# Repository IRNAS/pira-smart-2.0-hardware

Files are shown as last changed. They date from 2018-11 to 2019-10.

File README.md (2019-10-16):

# pira-smart-3.0-hardware

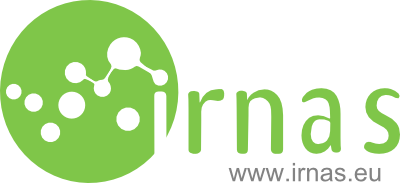
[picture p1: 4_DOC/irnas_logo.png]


PIRA Smart is a multifunctional device that can be used in any IoT project.

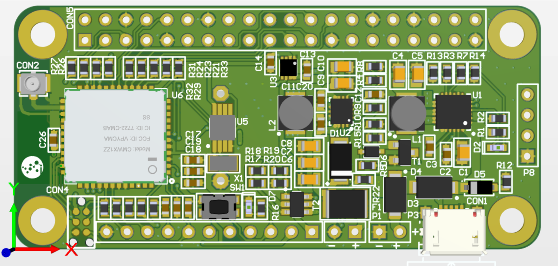
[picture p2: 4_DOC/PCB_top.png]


## Folder structure
 * folder [1_SCHEMATIC](https://github.com/IRNAS/pira-smart-2.0-hardware/tree/development/1_SCHEMATIC) includes Altium schematic files and PDF schematic
 * folder [2_PCB](https://github.com/IRNAS/pira-smart-2.0-hardware/tree/development/2_PCB) includes Altium PCB file, PDF PCB print and PDF 3D PCB print
 * folder [3_OUTPUT_FILES](https://github.com/IRNAS/pira-smart-2.0-hardware/tree/development/3_OUTPUT_FILES) includes Gerber and NC Drill files, PDF Assembly file and Bill of Material
 * folder [4_DOC](https://github.com/IRNAS/pira-smart-2.0-hardware/tree/development/4_DOC) includes 3D step model of PCB and photos of device
 * folder [5_ALTIUM_FILES](https://github.com/IRNAS/pira-smart-2.0-hardware/tree/development/5_ALTIUM_FILES) incudes all Altium Designer files (Libraries, Output job, Project document, ...)
 * folder [6_RELEASE](https://github.com/IRNAS/pira-smart-2.0-hardware/tree/development/6_RELEASE/pira-smart-PCB/v2_1) includes latest release [version 2.1](https://github.com/IRNAS/pira-smart-2.0-hardware/tree/development/6_RELEASE/pira-smart-PCB/v2_1)

## Specification

Device consists of:
 * Microcontroller module Murata Type ABZ - CMWX1ZZABZ:
   * Microcontroller STM (STM32L073)
   * LoRa connectivity Semtech (SX1276)
 * BLE - RN4871
 * RTC - ISL1208IU8Z-T7A
 * EEPROM with EUI - 24AA02E48T-I/OT
 * LDO regulator - MCP1810T-30I/J8A
 * Boost converter - TPS630701RNMT
 * Battery charger - BQ24296RGET
 * RPi connector
 * GPIO header
 * Tag connect for programming TC2030

Block diagram

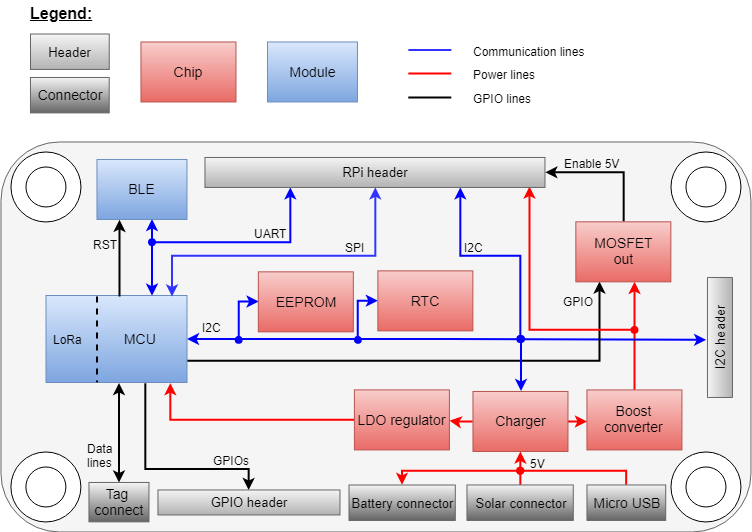
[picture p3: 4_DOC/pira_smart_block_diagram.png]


Features:
 * Single cell LiPo cell charging of up to 3A (multiple 18650 cells supported)
 * Solar panel charging (Voltaic systems 6W panels in parallel recommended)
 * USB charging
 * Advanced current limiting, to support wide array of chargers
 * Precise charging control via I2C (BQ24296RGET)
 * Battery temperature protection with thermistor
 * Battery reverse polarity protection and fuse (3A)
 * High-current battery output MOSFET
 * LoRa communication module with micro RF connector
 * Advanced power scheduling for robust applications:
   * ISL1208 RTC for configurable scheduled boot and timekeeping, with battery backup power supply to save power of the main battery
   * Configurable power-up sources (RTC, charging, etc.)

Dimensions:
 * Lenght: 65 mm
 * Height: 30 mm
 * PCB thickness: 1.6 mm

## License

All our projects are as usefully open-source as possible.

Hardware including documentation is licensed under [CERN OHL v.1.2. license](http://www.ohwr.org/licenses/cern-ohl/v1.2)

Firmware and software originating from the project is licensed under [GNU GENERAL PUBLIC LICENSE v3](http://www.gnu.org/licenses/gpl-3.0.en.html).

Open data generated by our projects is licensed under [CC0](https://creativecommons.org/publicdomain/zero/1.0/legalcode).

All our websites and additional documentation are licensed under [Creative Commons Attribution-ShareAlike 4 .0 Unported License](https://creativecommons.org/licenses/by-sa/4.0/legalcode).

What this means is that you can use hardware, firmware, software and documentation without paying a royalty and knowing that you'll be able to use your version forever. You are also free to make changes but if you share these changes then you have to do so on the same conditions that you enjoy.

Koruza, GoodEnoughCNC and IRNAS are all names and marks of Institut IRNAS Race. 
You may use these names and terms only to attribute the appropriate entity as required by the Open Licences referred to above. You may not use them in any other way and in particular you may not use them to imply endorsement or authorization of any hardware that you design, make or sell.

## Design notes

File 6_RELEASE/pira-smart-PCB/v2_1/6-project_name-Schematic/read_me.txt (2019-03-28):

Update Schematic Cover Page to RELEASED DD-MMM-YYYY
Place here PDF version of schematic

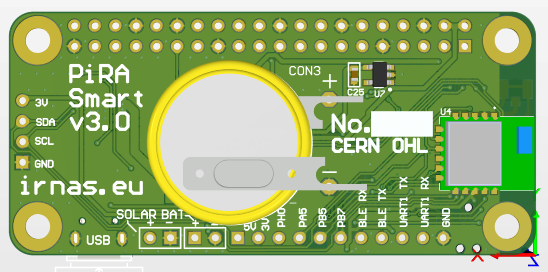
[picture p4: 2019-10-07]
4_DOC/PCB_bottom.png

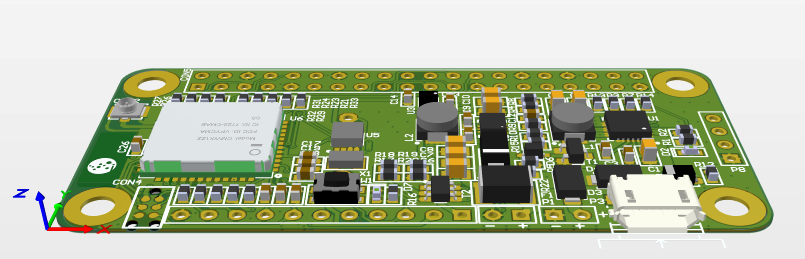
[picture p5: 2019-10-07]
4_DOC/PCB_angle.png

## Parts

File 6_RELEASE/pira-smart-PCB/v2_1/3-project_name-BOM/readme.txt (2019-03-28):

This folder includes:
- irnas readble BOM
- irnas simple sticker BOM

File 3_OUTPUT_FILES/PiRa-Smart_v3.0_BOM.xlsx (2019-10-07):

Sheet: Part List Report
 | Component list |  |  | PiRa-Smart
 | Source Data From: | pira-smart-PCB.PrjPcb |  |  | Contact:
 | Project: | pira-smart-PCB.PrjPcb
 | Variant: | None |  |  |  |  |  |  | IRNAS
 | Report Date: | 7. 10. 2019 | 21:36 |  |  |  |  |  | www.irnas.eu
 | Print Date: | 2019-10-07 | 21:36:31
# | Manufacturer Part Number 1 | Manufacturer 1 | Description | Footprint | Category | Quantity | Supplier 1 | Supplier Part Number 1 | Supplier Order Qty 1 | Supplier Stock 1 | Supplier Unit Price 1 | Supplier Subtotal 1 | Supplier Currency 1
1 |  |  | 10uf/0603/20% | CAP0603 |  | 2 | Farnell | 2820985
2 |  |  | MULTICOMP - MC0603B473K500CT - CAP, MLCC, X7R, 47NF, 50V, 0603 | CAP0603 |  | 1 | Farnell | 1759116
3 |  |  | Multilayer Ceramic Capacitors MLCC - SMD/SMT 0603 10uF 16volts X5R 10% | CAP0603 |  | 2 | Farnell | 2611923
4 |  |  | MURATA - GRM188R61C475KAAJD - CAP, MLCC, X5R, 4.7UF, 16V, 0603 | CAP0603 |  | 1 | Farnell | 2611924
5 |  |  | MURATA - GRM188R61C475KAAJD - CAP, MLCC, X5R, 4.7UF, 16V, 0603 | CAP0603 |  | 1 | Farnell | 2611924
6 |  |  | MURATA - GRM188R61H105KAALD - CAP, MLCC, X5R, 1UF, 50V, 0603 | CAP0603 |  | 2 | Farnell | 1845736
7 |  |  | MURATA - GRM188R61H105KAALD - CAP, MLCC, X5R, 1UF, 50V, 0603 | CAP0603 |  | 1 | Farnell | 1845736
8 |  |  | MURATA - GRM188R71C104KA01J - CAP, MLCC, X7R, 0.1UF, 16V, 0603 | CAP0603 |  | 4 | Farnell | 2688519
9 |  |  | SMD Multilayer Ceramic Capacitor, 2.2 µF, 6.3 V, 0603 [1608 Metric], ± 10%, X5R, MC Series | CAP0603 |  | 1 | Farnell | 1759392
10 |  |  | MULTICOMP - MC0805X226M6R3CT - CAP, MLCC, X5R, 22UF, 0805 | CAP0805 |  | 4 | Farnell | 1759415
11 |  |  | TDK - CGA4J1X5R1C106K125AC - CAP, MLCC, X5R, 10UF, 16V, 0805 | CAP0805 |  | 4 | Farnell | 2320856
12 |  |  | LITTELFUSE - MINISMDC150F/24-2 - POLYSWITCH, SMD, 1812, 1.5A | Chip2PinSM127P600-8N |  | 1 | Farnell | 1345929
13 |  |  | BATT LITH COIN 3V CELL PC PINS | CR-2032/VCN |  | 1 | Farnell | 1892670
14 |  |  | MURATA - FDSD0420-H-1R5M=P3 - INDUCTOR, SHIELDED, 1.5UH, 5.1A, 20% | FDSD0402 |  | 2 | Farnell | 2530091
15 |  |  | Header, 4-Pin | HDR1X4 |  | 1 |  | Header 2.54mm
16 |  |  | Header, 11-Pin | HDR1X11 |  | 1 |  | Header 2.54mm
17 |  |  | Header, 20-Pin, Dual row | HDR2X20 |  | 1
18 |  |  | BROADCOM LIMITED - HSMS-C190 - LED, RED, 10MCD, 626NM | LED0603 |  | 1 | Farnell | 2497356
19 |  |  | HSME-C191 - LED, Green, SMD, 0603, 20 mA, 2.1 V, 572 nm | LED0603 |  | 1 | Farnell | 1219743
20 |  |  | CRYSTAL, 32.768KHZ, 12.5PF, SMD | LFXTAL009678 |  | 1 | Farnell | 2449398
21 |  |  | Lora Module Murata | Lora Module ES0 |  | 1 | Farnell | 2802546
22 |  |  | IC LI+ CHARGER PWR MGMT 24VQFN | QFN4x4 | Integrated Circuits (ICs) | 1 | Farnell | 2373541
23 |  |  | BOURNS - CR0603-J/-000ELF - RES, THICK FILM, 0R, 5%, 0.1W, 0603 | RES0603 |  | 9 | Farnell | 2008343
24 |  |  | MULTICOMP - MC0063W06031100R - RES, THICK FILM, 100R, 1%, 0.063W, 0603 | RES0603 |  | 2 | Farnell | 2447227
25 |  |  | MULTICOMP - MC0063W06031100R - RES, THICK FILM, 100R, 1%, 0.063W, 0603 | RES0603 |  | 2 | Farnell | 9330364
26 |  |  | MULTICOMP - MCMR06X102 JTL - RES, CERAMIC, 1K, 5%, 0.1W, 0603 | RES0603 |  | 1 | Farnell | 2073354
27 |  |  | MULTICOMP - MCMR06X103 JTL - RES, CERAMIC, 10K, 5%, 0.1W, 0603 | RES0603 |  | 3 | Farnell | 2073356
28 |  |  | MULTICOMP - MCMR06X104 JTL - RES, CERAMIC, 100K, 5%, 0.1W, 0603 | RES0603 |  | 4 | Farnell | 2073357
29 |  |  | MULTICOMP - MCMR06X471 JTL - RES, CERAMIC, 470R, 5%, 0.1W, 0603 | RES0603 |  | 2 | Farnell | 2073513
30 |  |  | MULTICOMP - MCMR06X4701FTL - RES, CERAMIC, 4K7, 1%, 0.1W, 0603 | RES0603 |  | 2 | Farnell | 2073509
31 |  |  | MULTICOMP - MCMR06X5601FTL - RES, CERAMIC, 5K6, 1%, 0.1W, 0603 | RES0603 |  | 1 | Farnell | 2073537
32 |  |  | MULTICOMP - MCWR06X1503FTL - RES, THICK FILM, 150KOHM, 1%, 0.1W | RES0603 |  | 1 | Farnell | 2447254
33 |  |  | MULTICOMP - MCWR06X2200FTL - RES, THICK FILM, 220R, 1%, 0.1W, 0603 | RES0603 |  | 1 | Farnell | 2447298
34 |  |  | MULTICOMP - MCWR06X3302FTL - RES, THICK FILM, 33K, 1%, 0.1W, 0603 | RES0603 |  | 1 | Farnell | 2447342
35 |  |  | MULTICOMP - MCWR06X3901FTL - RES, THICK FILM, 3K9, 1%, 0.1W, 0603 | RES0603 |  | 1 | Farnell | 2447363
36 |  |  | Thermistor, NTC, 10 kohm, B57321V2 Series, 4000 K, SMD, 0603 [1608 Metric] | RES0603 |  | 1 | Farnell | 1299914
37 |  |  | Thick Film Resistors - SMD 1/10watt 226Kohms 1% | RES0603 |  | 1 | Farnell | 2138531
38 |  |  | VISHAY - RCA060310R0FKEA - RES, AUTO, THICK FILM, 10R, 1%, 0603 | RES0603 |  | 1 | Farnell | 2616585
39 |  |  | MICROCHIP RN4871-V/RM118 BLE MOD W/ANTENNA, 2.442MHZ, 0.1DBI New | RN4871 |  | 1 | Farnell | 2664514
40 |  |  | VISHAY - RS1J-E3/61T.. - DIODE, FAST, 1A, 600V, SMD | SMC/DO-214AC |  | 1 | Farnell | 9550143
41 |  |  | DIODES INC. - BZT52C6V2 - DIODE, ZENER, 6.2V, 0.5W, SOD-123 | SOD123 |  | 1 | Farnell | 1902438
42 |  |  | ON SEMICONDUCTOR - MM3Z3V0T1G - ZENER DIODE, 200MW, 3V, SOD-323 | SOD-323 2L |  | 1 | Farnell | 2463510
43 |  |  | VISHAY - SE30AFG-M3/6A - RECTIFIER, ESD, 400V, 3A, DO-221AC | SODFL127P600-8N |  | 2 | Farnell | 2313878
44 |  |  | MICROCHIP 24AA02E48T-I/OT EEPROM, EUI-48 Node Identity, 2 Kbit, 2 BLK (128K x 8bit), 400 kHz, I2C, SOT-23, 5 Pins | SOT95P280X145-5N |  | 1 | Farnell | 1688855
45 |  |  | ON SEMICONDUCTOR/FAIRCHILD - MMBT3904 - TRANSISTOR, NPN, SOT-23 | SOT23127P600-8N |  | 1 | Farnell | 9846727
46 |  |  | SWITCH TACTILE SPST-NO 0.05A 32V | Tactile button |  | 1 | C&K Components | 2845727
47 |  |  | IC RTC/CALENDAR I2C LP 8MSOP | TSOP65P500X110-8N |  | 1 | Farnell | 2543322
48 |  |  | DIODES INC. - DMG6602SVT - MOSFET, NP CH, , 30V, 3.4, ATSOT23 | TSOT26 |  | 1 | Farnell | 2061522
49 |  |  | CONN UMC JACK STR 50 OHM SMD | ufl connector smd | Connectors, Interconnects | 1 | Farnell | 1688077
50 |  |  | IC REG LINEAR 3V 150MA 8VDFN | VDFN_2x2 |  | 1 | Farnell | 2678433
51 |  |  | TEXAS INSTRUMENTS - TPS630701RNMT - DC/DC CONV, BUCK-BOOST, 2.4MHZ, VQFN-15 | VQFN TPS |  | 1 | Farnell | 2643432
 |  |  |  |  |  | 82 |  |  | 0 |  |  | 0
Approved |  |  |  | Notes
 |  |  |  | pcs: |  | 20 |  | Total |  | 0 |  | <none>
 |  |  |  |  |  |  |  | Price for 1pcs |  | 0.00 |  | <none>

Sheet: Project Information
Project Full Path | D:\OneDrive\IRNAS-Common\_NEW-IRNAS-COMMON\Irnas-Pira\pira-smart-2.0-hardware\pira-smart-PCB\pira-smart-PCB.PrjPcb
Project Filename | pira-smart-PCB.PrjPcb
Variant Name | None
Data-Source Filename | pira-smart-PCB.PrjPcb
Data-Source Full Path | D:\OneDrive\IRNAS-Common\_NEW-IRNAS-COMMON\Irnas-Pira\pira-smart-2.0-hardware\pira-smart-PCB\pira-smart-PCB.PrjPcb
Title | BOM for Project [pira-smart-PCB.PrjPcb] (No PCB Document Selected)
Total Quantity | 82
Report Time | 21:36
Report Date | 7. 10. 2019
Report Date & Tine | 7. 10. 2019 21:36
Output Name | BOM
Output Type | BOM_PartType
Output Generator Name | BOM
Output Generator Description | Bill of Materials

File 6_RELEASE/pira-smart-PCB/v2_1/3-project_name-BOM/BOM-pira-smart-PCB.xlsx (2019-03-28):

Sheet: Part List Report
 | Component list |  |  | PiRa-Smart
 | Source Data From: | pira-smart-PCB.PrjPcb |  |  | Contact:
 | Project: | pira-smart-PCB.PrjPcb
 | Variant: | None |  |  |  |  |  |  | IRNAS
 | Report Date: | 28/03/2019 | 3:05 PM |  |  |  |  |  | www.irnas.eu
 | Print Date: | 2019-03-28 | 15:06:00
# | Manufacturer Part Number 1 | Manufacturer 1 | Description | Footprint | Designator | Quantity | Supplier 1 | Supplier Part Number 1 | Supplier Order Qty 1 | Supplier Stock 1 | Supplier Unit Price 1 | Supplier Subtotal 1 | Supplier Currency 1
1 | CC0805KKX7R8BB225 | Yageo | Multilayer Ceramic Capacitors MLCC - SMD/SMT 2.2uF 25V X7R 10% | CAP0805 | C14 | 1 | Farnell | 1458904 | 20 | 42154 | 0.37 | 7.49 | EUR
2 | SE30AFG-M3/6A | Vishay Semiconductors | VISHAY - SE30AFG-M3/6A - RECTIFIER, ESD, 400V, 3A, DO-221AC | SODFL127P600-8N | D3, D4 | 2 | Farnell | 2313878 | 40 | 23380 | 0.30 | 12.08 | EUR
3 | RS1J-E3/61T | Vishay Intertechnology | VISHAY - RS1J-E3/61T.. - DIODE, FAST, 1A, 600V, SMD | SMC/DO-214AC | D1 | 1 | Farnell | 9550143 |  | 0
4 | RCA060310R0FKEA | Vishay Dale | VISHAY - RCA060310R0FKEA - RES, AUTO, THICK FILM, 10R, 1%, 0603 | RES0603 | R12 | 1 | Farnell | 2616585 | 20 | 3 | 0.04 | 0.85 | EUR
5 | CRCW0603226KFKEA | Vishay | Thick Film Resistors - SMD 1/10watt 226Kohms 1% | RES0603 | R29 | 1 | Farnell | 2138531 | 20 | 2400 | 0.02 | 0.44 | EUR
6 | BQ24296RGET | Texas Instruments | IC LI+ CHARGER PWR MGMT 24VQFN | QFN4x4 | U1 | 1 | Farnell | 2373541 | 20 | 0 | 2.06 | 41.11 | EUR
7 | TPS78326DDCT | Texas Instruments | IC REG LINEAR 2.6V 150MA SOT23-5 | SOT95P280X145-5N | U3 | 1 | Digi-Key | 296-35542-1-ND | 20 | 873 | 0.76 | 15.23 | EUR
8 | TPS630701RNMT | Texas Instruments | TEXAS INSTRUMENTS - TPS630701RNMT - DC/DC CONV, BUCK-BOOST, 2.4MHZ, VQFN-15 | VQFN TPS | U2 | 1 | Farnell | 2643432 | 20 | 0 | 2.18 | 43.70 | EUR
9 | CR-2032/VCN | Panasonic BSG | BATT LITH COIN 3V CELL PC PINS | CR-2032/VCN | CON3 | 1 | Farnell | 1892670 | 20 | 142 | 0.95 | 19.03 | EUR
10 | MMBT3904 | ON Semiconductor / Fairchild | ON SEMICONDUCTOR/FAIRCHILD - MMBT3904 - TRANSISTOR, NPN, SOT-23 | SOT23127P600-8N | T1 | 1 | Farnell | 9846727 |  | 0
11 | MM3Z3V0T1G | ON Semiconductor | ON SEMICONDUCTOR - MM3Z3V0T1G - ZENER DIODE, 200MW, 3V, SOD-323 | SOD-323 2L | D6 | 1 | Farnell | 2463510 | 20 | 12995 | 0.13 | 2.65 | EUR
12 | CMWX1ZZABZ-091 | Murata | Lora Module Murata | Lora Module ES0 | U6 | 1 | Farnell | 2802546 | 20 | 1522 | 13.94 | 278.85 | EUR
13 | GRM188R61C106KAALD | Murata | Multilayer Ceramic Capacitors MLCC - SMD/SMT 0603 10uF 16volts X5R 10% | CAP0603 | C11, C20 | 2 | Farnell | 2611923 | 40 | 149339 | 0.33 | 13.20 | EUR
14 | FDSD0420-H-1R5M=P3 | Murata | MURATA - FDSD0420-H-1R5M=P3 - INDUCTOR, SHIELDED, 1.5UH, 5.1A, 20% | FDSD0402 | L1, L2 | 2 | Farnell | 2530091 | 50 | 1443 | 0.47 | 23.61 | EUR
15 | GRM188R61C475KAAJD | Murata | MURATA - GRM188R61C475KAAJD - CAP, MLCC, X5R, 4.7UF, 16V, 0603 | CAP0603 | C2 | 1 | Farnell | 2611924 | 20 | 38369 | 0.30 | 5.99 | EUR
16 | GRM188R61H105KAALD | Murata | MURATA - GRM188R61H105KAALD - CAP, MLCC, X5R, 1UF, 50V, 0603 | CAP0603 | C13, C16, C17 | 3 | Farnell | 1845736 | 100 | 0 | 0.23 | 22.55 | EUR
17 | GRM188R71C104KA01J | Murata | MURATA - GRM188R71C104KA01J - CAP, MLCC, X7R, 0.1UF, 16V, 0603 | CAP0603 | C12, C15, C18, C25 | 4 | Farnell | 2688519 |  | 0
18 | MCMR06X103JTL, [NoParam] | Multicomp, [NoParam] | MULTICOMP - MCMR06X103 JTL - RES, CERAMIC, 10K, 5%, 0.1W, 0603, 10K resistor | RES0603 | R6, R9, R10, R15, R21, R23, R28, R31, R35 | 9 | Farnell, [NoParam] | 2073356, [NoParam]
19 | MCWR06X1000FTL | Multicomp | MULTICOMP - MC0063W06031100R - RES, THICK FILM, 100R, 1%, 0.063W, 0603 | RES0603 | R18, R19 | 2 | Farnell | 2447227 | 40 | 581300 | 0.01 | 0.23 | EUR
20 | MC0603B473K500CT | Multicomp | MULTICOMP - MC0603B473K500CT - CAP, MLCC, X7R, 47NF, 50V, 0603 | CAP0603 | C3 | 1 | Farnell | 1759116 | 20 | 45680 | 0.03 | 0.60 | EUR
21 | MC0805X226M6R3CT | Multicomp | MULTICOMP - MC0805X226M6R3CT - CAP, MLCC, X5R, 22UF, 0805 | CAP0805 | C7, C8, C9, C10 | 4 | Farnell | 1759415 |  | 0
22 | MCMR06X104JTL | Multicomp | MULTICOMP - MCMR06X104 JTL - RES, CERAMIC, 100K, 5%, 0.1W, 0603 | RES0603 | R17, R20, R30, R32 | 4 | Farnell | 2073357 | 100 | 5949 | 0.01 | 0.51 | EUR
23 | MCMR06X471JTL | Multicomp | MULTICOMP - MCMR06X471 JTL - RES, CERAMIC, 470R, 5%, 0.1W, 0603 | RES0603 | R1, R14 | 2 | Farnell | 2073513 | 40 | 4765 | 0.01 | 0.23 | EUR
24 | MCMR06X4701FTL | Multicomp | MULTICOMP - MCMR06X4701FTL - RES, CERAMIC, 4K7, 1%, 0.1W, 0603 | RES0603 | R24, R25 | 2 | Farnell | 2073509 | 40 | 12988 | 0.01 | 0.44 | EUR
25 | MCMR06X5601FTL | Multicomp | MULTICOMP - MCMR06X5601FTL - RES, CERAMIC, 5K6, 1%, 0.1W, 0603 | RES0603 | R3 | 1 | Farnell | 2073537 | 20 | 4970 | 0.01 | 0.21 | EUR
26 | MCWR06X1503FTL | Multicomp | MULTICOMP - MCWR06X1503FTL - RES, THICK FILM, 150KOHM, 1%, 0.1W | RES0603 | R8 | 1 | Farnell | 2447254 | 20 | 5752 | 0.01 | 0.12 | EUR
27 | MCWR06X2200FTL | Multicomp | MULTICOMP - MCWR06X2200FTL - RES, THICK FILM, 220R, 1%, 0.1W, 0603 | RES0603 | R7 | 1 | Farnell | 2447298 | 20 | 119967 | 0.01 | 0.12 | EUR
28 | MCWR06X3302FTL | Multicomp | MULTICOMP - MCWR06X3302FTL - RES, THICK FILM, 33K, 1%, 0.1W, 0603 | RES0603 | R13 | 1 | Farnell | 2447342 |  | 0
29 | MCWR06X3901FTL | Multicomp | MULTICOMP - MCWR06X3901FTL - RES, THICK FILM, 3K9, 1%, 0.1W, 0603 | RES0603 | R5 | 1 | Farnell | 2447363 |  | 0
30 | MC0805X106K160CT | Multicomp | TDK - CGA4J1X5R1C106K125AC - CAP, MLCC, X5R, 10UF, 16V, 0805 | CAP0805 | C1, C4, C5, C6 | 4 | Farnell | 2320856 |  | 0
31 | 24AA02E48T-I/OT | Microchip | MICROCHIP 24AA02E48T-I/OT EEPROM, EUI-48 Node Identity, 2 Kbit, 2 BLK (128K x 8bit), 400 kHz, I2C, SOT-23, 5 Pins | SOT95P280X145-5N | U7 | 1 | Farnell | 1688855 | 20 | 8258 | 0.20 | 4.02 | EUR
32 | RN4871-V/RM118 | Microchip | MICROCHIP RN4871-V/RM118 BLE MOD W/ANTENNA, 2.442MHZ, 0.1DBI New | RN4871 | U4 | 1 | Farnell | 2664514 | 20 | 1997 | 6.20 | 124.04 | EUR
33 | MINISMDC150F/24-2 | Littelfuse | LITTELFUSE - MINISMDC150F/24-2 - POLYSWITCH, SMD, 1812, 1.5A | Chip2PinSM127P600-8N | F1 | 1 | Farnell | 1345929 | 20 | 6653 | 0.54 | 10.85 | EUR
34 | C0603C106M8PACTU | KEMET | 10uf/0603/20% | CAP0603 | C19, C24 | 2 | Farnell | 2820985 | 40 | 438 | 0.75 | 29.84 | EUR
35 | C0402C101K5RACTU | KEMET | Cap Ceramic 100pF 50V X7R 10% SMD 0402 125C T/R | CAP0402 | C21 | 1 | Farnell | 2522375 | 20 | 8170 | 0.04 | 0.88 | EUR
36 | LFXTAL009678 | IQD | CRYSTAL, 32.768KHZ, 12.5PF, SMD | LFXTAL009678 | X1 | 1 | Farnell | 2449398 | 20 | 3194 | 0.45 | 8.97 | EUR
37 | ISL1208IU8Z-T7A | Intersil | IC RTC/CALENDAR I2C LP 8MSOP | TSOP65P500X110-8N | U5 | 1 | Farnell | 2543322 |  | 0
38 | U.FL-R-SMT-1(10) | Hirose | CONN UMC JACK STR 50 OHM SMD | ufl connector smd | CON2, CON4 | 2 | Farnell | 1688077 | 40 | 91659 | 0.82 | 32.64 | EUR
39 | BZT52C6V2 | Diodes Zetex | DIODES INC. - BZT52C6V2 - DIODE, ZENER, 6.2V, 0.5W, SOD-123 | SOD123 | D5 | 1 | Farnell | 1902438 | 25 | 6938 | 0.09 | 2.35 | EUR
40 | DMG6602SVT | Diodes | DIODES INC. - DMG6602SVT - MOSFET, NP CH, , 30V, 3.4, ATSOT23 | TSOT26 | T2 | 1 | Farnell | 2061522 |  | 0
41 | HSMS-C190 | Broadcom | BROADCOM LIMITED - HSMS-C190 - LED, RED, 10MCD, 626NM | LED0603 | D2 | 1 | Farnell | 2497356 | 20 | 0 | 0.15 | 2.91 | EUR
42 | CR0603-J/-000ELF | Bourns | BOURNS - CR0603-J/-000ELF - RES, THICK FILM, 0R, 5%, 0.1W, 0603 | RES0603 | R2, R4, R11, R16, R22, R26, R27, R33, R34, R37, R38 | 11 | Farnell | 2008343 | 250 | 34017 | 0.01 | 2.61 | EUR
43 |  |  | Cap 0402 footprint only | CAP0402 | C22, C23 | 2
44 |  |  | Header, 3-Pin | HDR1X3 | P2 | 1
45 |  |  | Header, 4-Pin | HDR1X4 | P8 | 1
46 |  |  | SWITCH TACTILE SPST-NO 0.05A 32V | Tactile button | SW1 | 1 | C&K Components | 2845727
 |  |  |  |  |  | 87 |  |  | 1205 |  |  | 708.33622
Approved |  |  |  | Notes
 |  |  |  | pcs: |  | 20 |  | Total |  | 708.33622 |  | EUR
 |  |  |  |  |  |  |  | Price for 1pcs |  | 35.42 |  | EUR

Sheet: Project Information
Project Full Path | C:\Users\vojislav\Documents\pira-smart-2.0-hardware\pira-smart-PCB\pira-smart-PCB.PrjPcb
Project Filename | pira-smart-PCB.PrjPcb
Variant Name | None
Data-Source Filename | pira-smart-PCB.PrjPcb
Data-Source Full Path | C:\Users\vojislav\Documents\pira-smart-2.0-hardware\pira-smart-PCB\pira-smart-PCB.PrjPcb
Title | BOM for Project [pira-smart-PCB.PrjPcb] (PCB Document : pira-smart-pcb.PcbDoc)
Total Quantity | 87
Report Time | 3:05 PM
Report Date | 28/03/2019
Report Date & Tine | 28/03/2019 3:05 PM
Output Name | BOM
Output Type | BOM_PartType
Output Generator Name | BOM
Output Generator Description | Bill of Materials

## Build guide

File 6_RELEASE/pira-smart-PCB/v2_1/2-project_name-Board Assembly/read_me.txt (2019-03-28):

Place following files here:

- Mechanical Drawing (Board dimensions, holes position, ..)
- TOP and BOTTOM Assembly Drawing (Component position with Reference Designator)
- Pick and Place csv
- 3D Model pictures TOP and BOTTOM

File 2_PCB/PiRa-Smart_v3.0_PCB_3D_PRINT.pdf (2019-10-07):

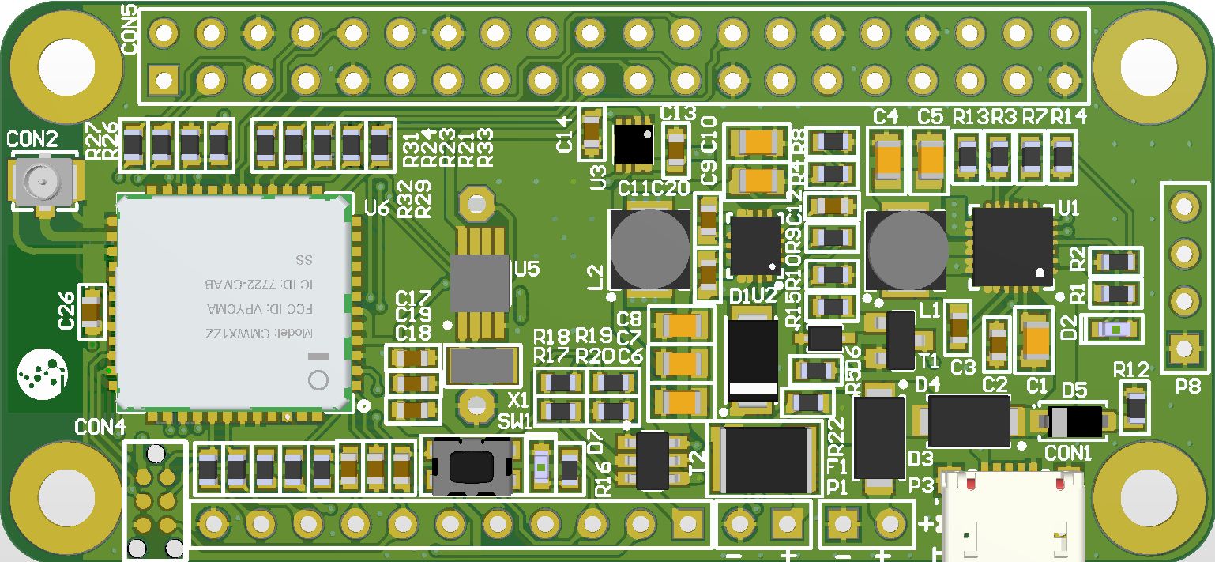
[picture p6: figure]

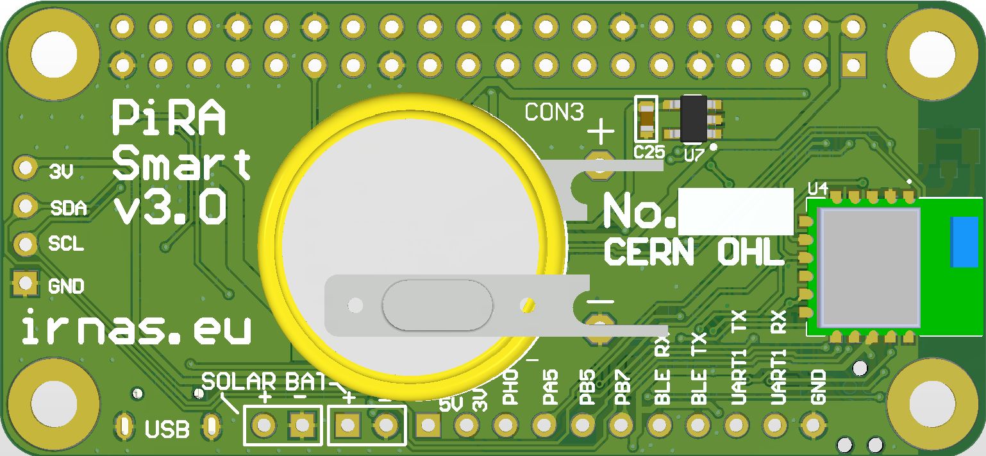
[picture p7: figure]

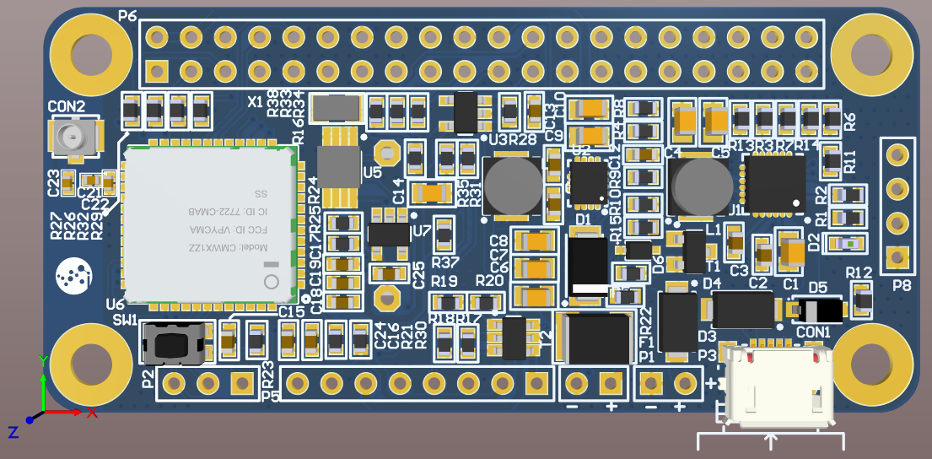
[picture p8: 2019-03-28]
6_RELEASE/pira-smart-PCB/v2_1/2-project_name-Board Assembly/top_Capture.PNG

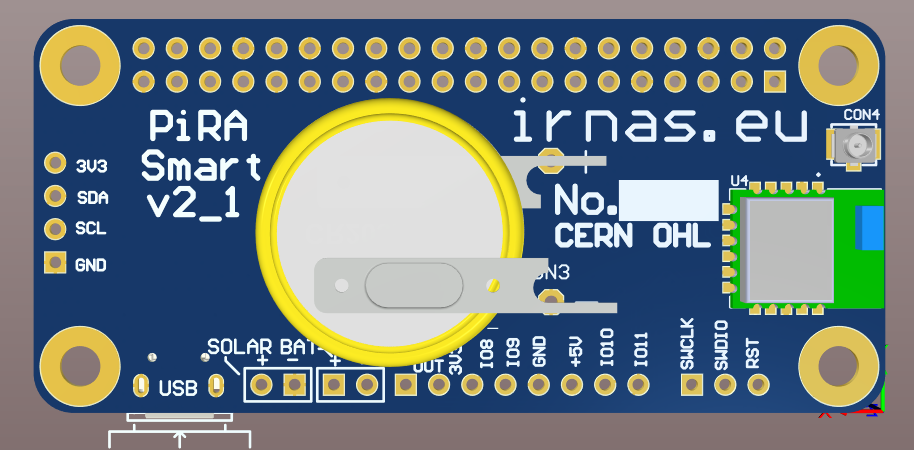
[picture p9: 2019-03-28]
6_RELEASE/pira-smart-PCB/v2_1/2-project_name-Board Assembly/bot_Capture.PNG

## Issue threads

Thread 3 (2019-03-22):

Hardware changes to achive current consumption of 30,4 uA #3

MarkoSagadin, 2019-03-22:
4,7 kohm resistor 28 is replaced with 100k ohms.

Closed 2022-03-04.

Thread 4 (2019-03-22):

Hardware changes to achive current consumption of 30,4 uA #4

MarkoSagadin, 2019-03-22:
Reset line from BLE module has to be connected to GPIO pin of MURATA module, this is needed to exit dormant (shutdown) mode.

Closed 2022-03-04.

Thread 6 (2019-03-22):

Hardware changes to achive current consumption of 30,4 uA #6

MarkoSagadin, 2019-03-22:
I2C FET is taken off, VCC is short circuited to i2C_VCC.

Closed 2022-03-04.

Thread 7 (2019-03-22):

New regulator for internal operation

MarkoSagadin, 2019-03-22:
Old buck converter was replaced with LDO TPS783.LDO is now converting from VBAT to VCC.

VojislavM, 2019-03-26:
This regulator will power:
* Murata LoRa module and main processor
* RTC
* EEPROM
* BT MODLE

selected LDO regulator is TPS78326DDCT with output voltage of 2.6V
Note: this could be a problem for the RTC because it has minimum operating voltage at 2.7V, but the tripping voltage for the backup battery is 2.2V. Need to test

SloMusti, 2019-03-26:
The regulator can be changes to 2.7 or 2.8V voltage no problem. LiPo Battery protection cut-off is at 2.8V.

VojislavM, 2019-03-26:
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

Resistors R31 and R35 are seledted based on the LDO used in the design. There are several optins for the LDO from series TPS783 and TPS 780.
This way we can use fixed, dual level, or adjustable output form the regulator.

Closed 2022-03-04.

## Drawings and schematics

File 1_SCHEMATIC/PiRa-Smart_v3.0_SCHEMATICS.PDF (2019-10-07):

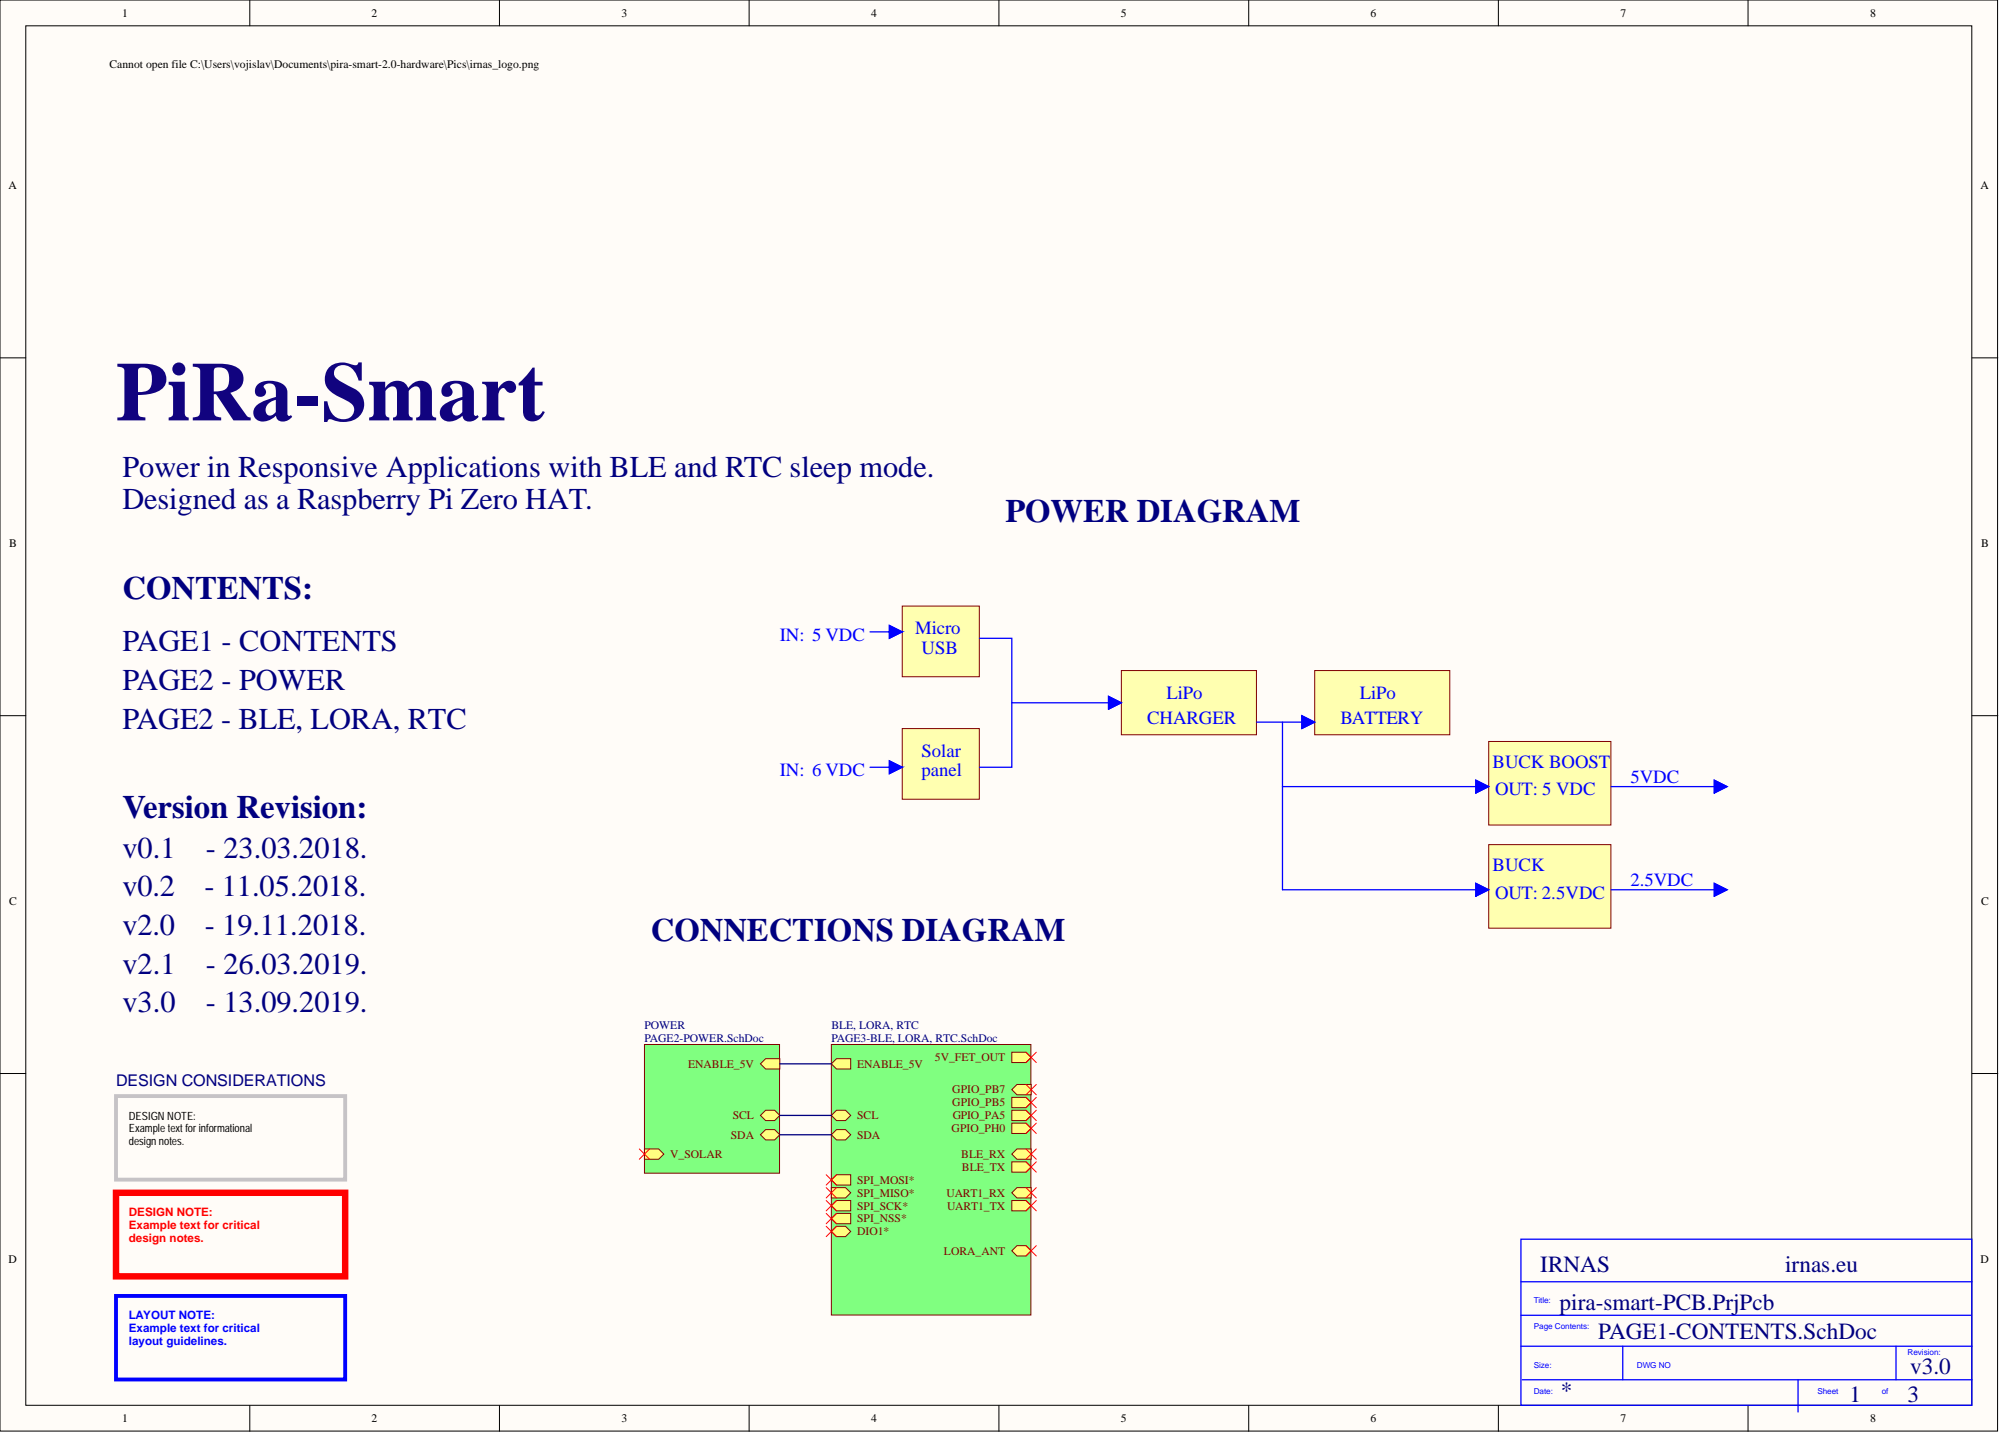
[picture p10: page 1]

Cannot open file C:\Users\vojislav\Documents\pira-smart-2.0-hardware\Pics\irnas_logo.png

Power in Responsive Applications with BLE and RTC sleep mode.
Designed as a Raspberry Pi Zero HAT.

BLE, LORA, RTC
PAGE3-BLE, LORA, RTC.SchDoc

DESIGN NOTE:
Example text for informational
design notes.

Example text for critical

pira-smart-PCB.PrjPcb
PAGE1-CONTENTS.SchDoc

LAYOUT NOTE:
layout guidelines.

Size: | DWG NO | Revision: v3.0

Date: | Sheet of

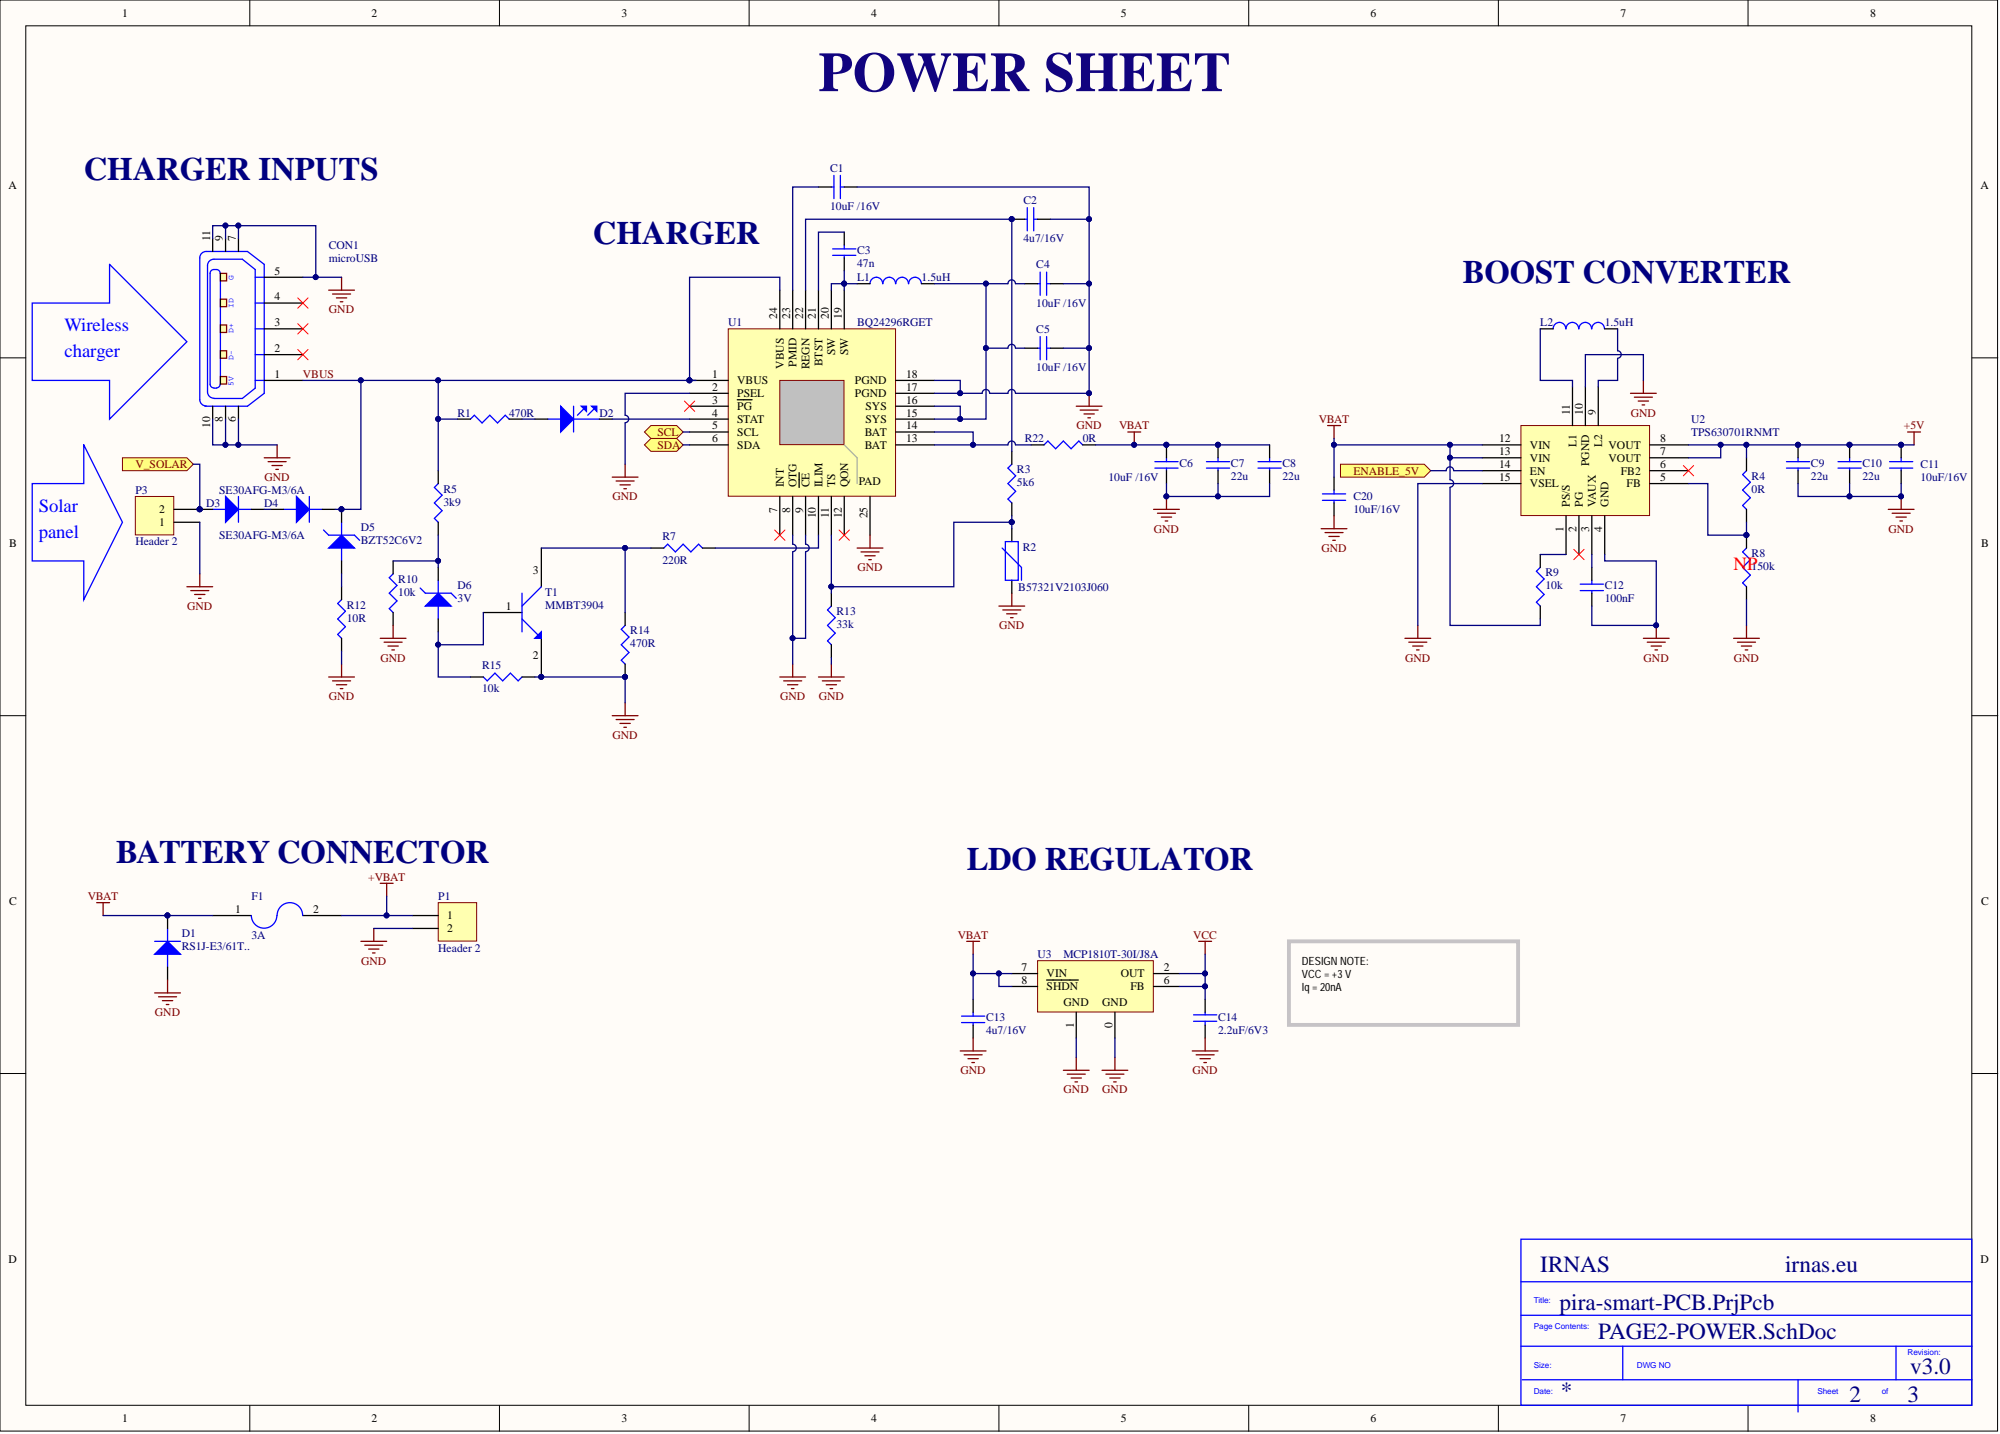
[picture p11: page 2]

SW 19 SW 20 BTST 21 REGN 22 PMID 23 VBUS 24

VBUS 1

pira-smart-PCB.PrjPcb
PAGE2-POWER.SchDoc

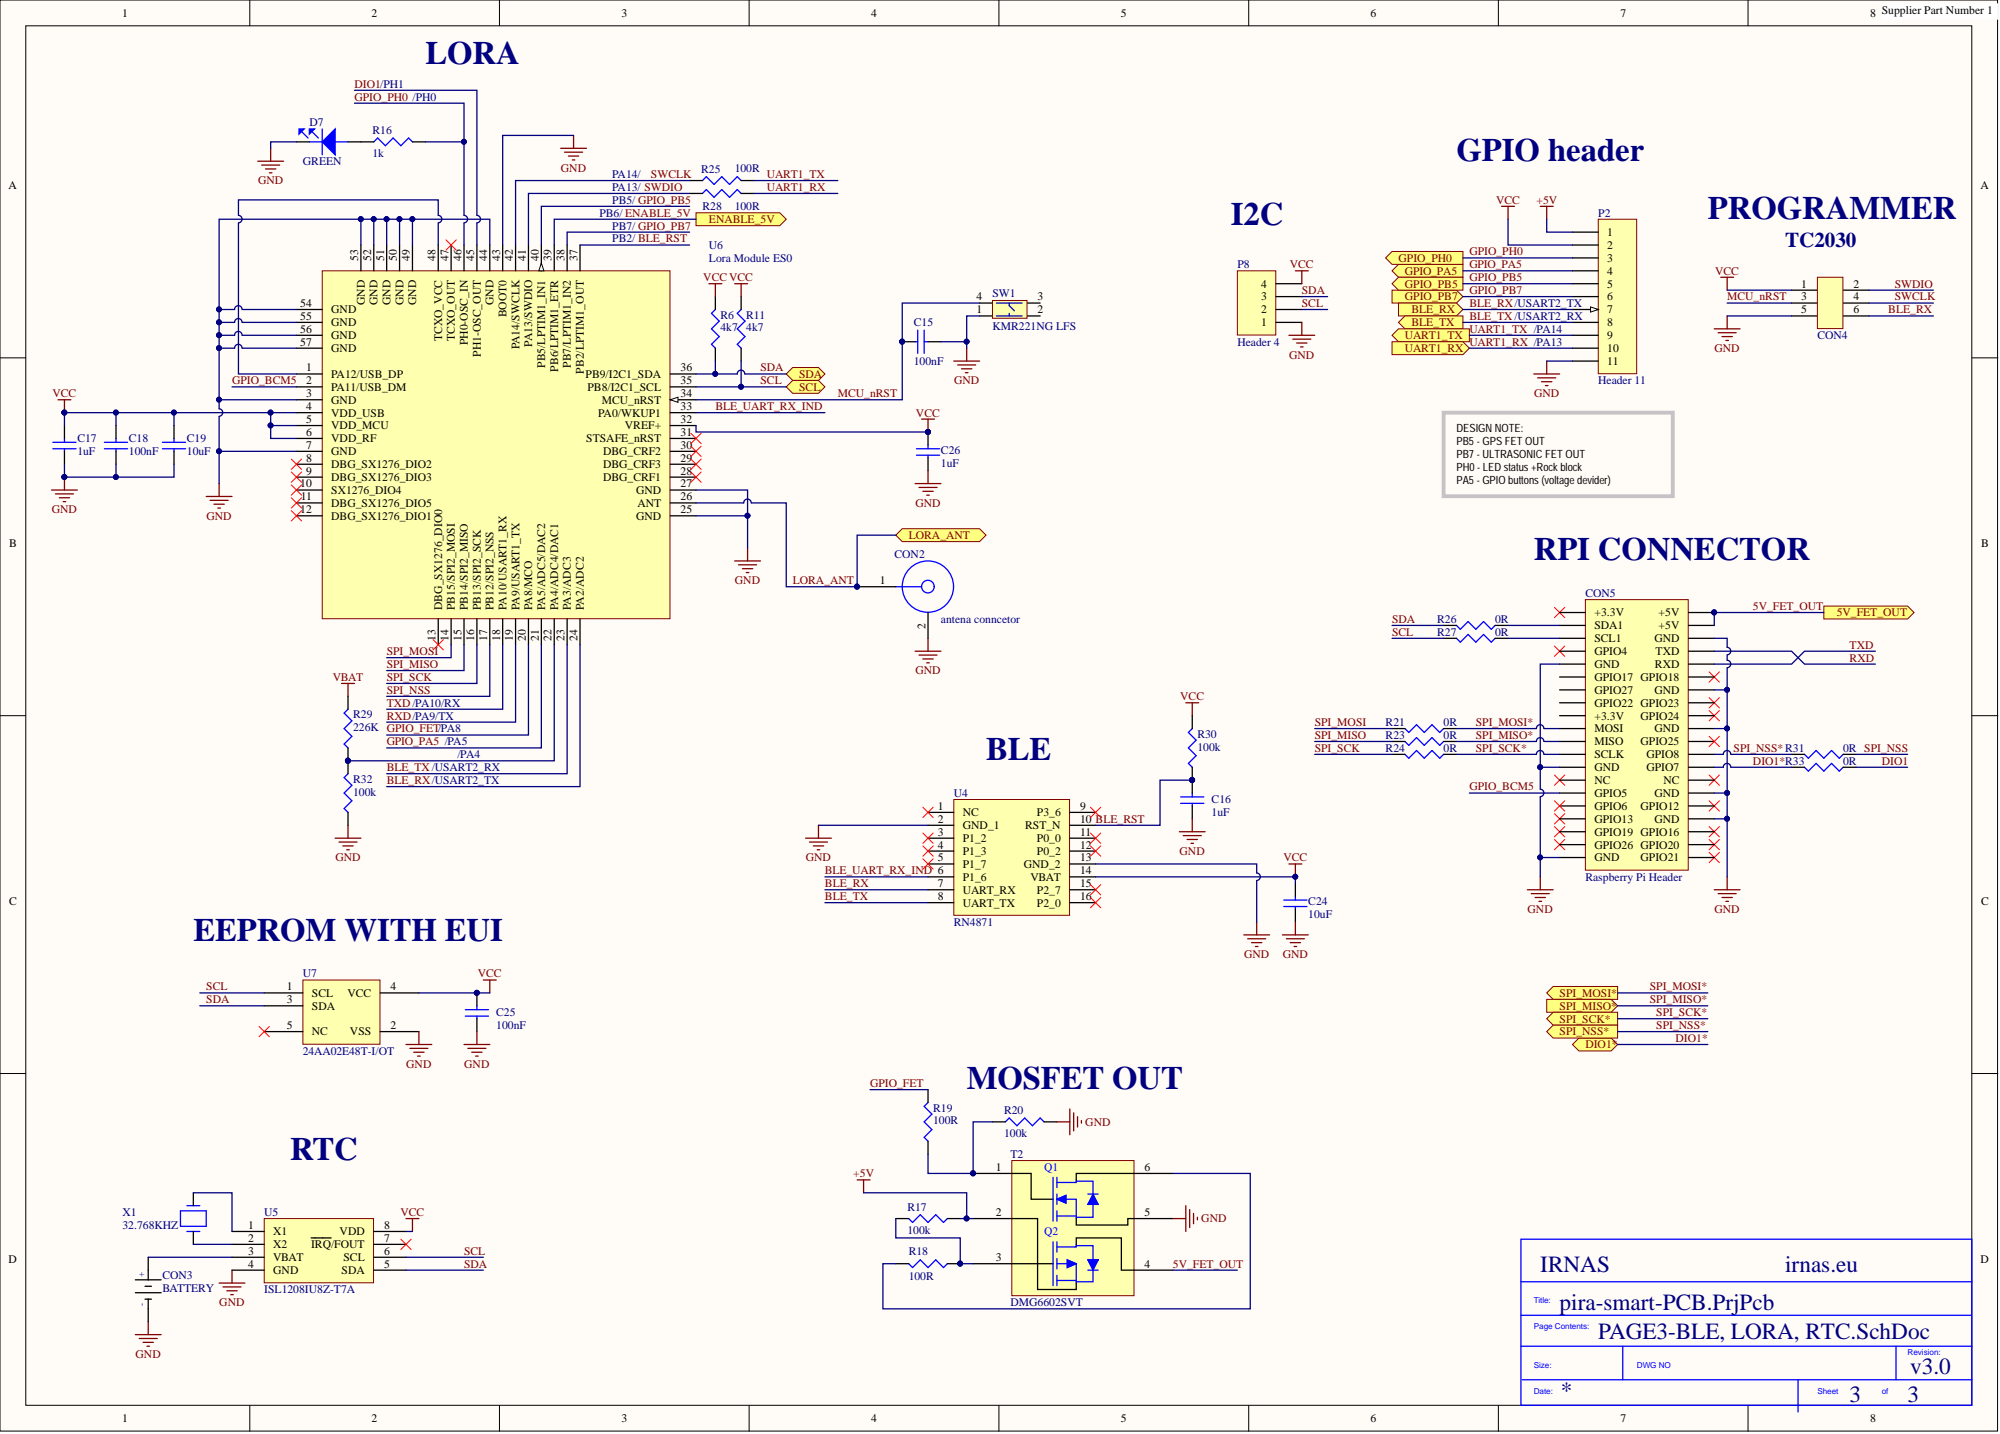
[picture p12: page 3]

GND 50 GND 51 GND 52 GND 53

GND 55
GND 56
GND 57

PA12/USB_DP 1

MCU_nRST

VDD_USB 4

VDD_RF 6

DESIGN NOTE:
PB5 - GPS FET OUT
PB7 - ULTRASONIC FET OUT
PH0 - LED status +Rock block
PA5 - GPIO buttons (voltage devider)

pira-smart-PCB.PrjPcb
PAGE3-BLE, LORA, RTC.SchDoc

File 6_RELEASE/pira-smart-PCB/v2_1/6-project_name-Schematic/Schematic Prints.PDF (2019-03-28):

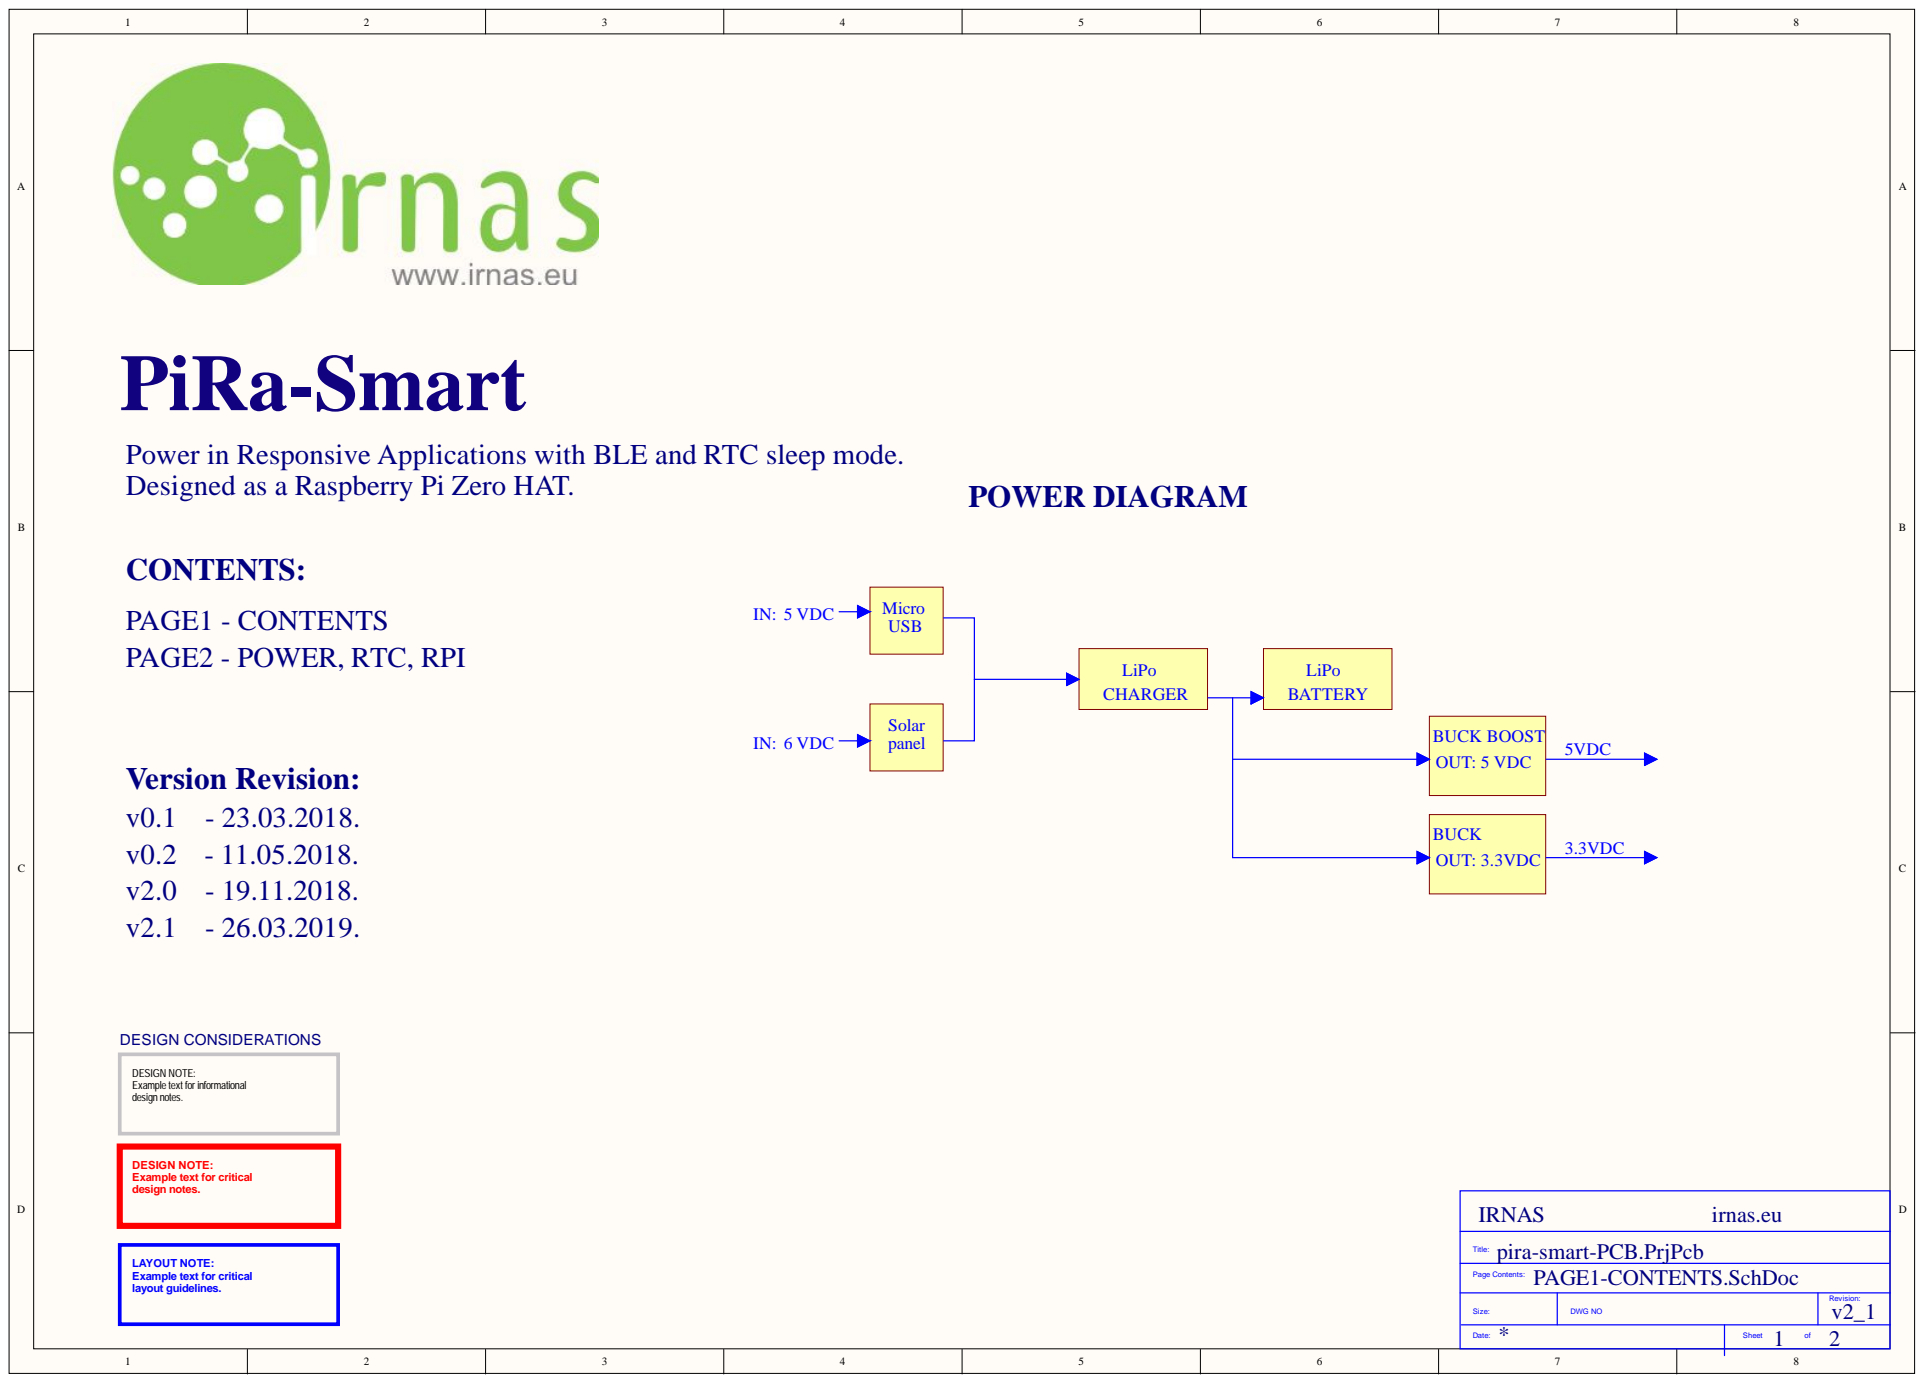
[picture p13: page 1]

Power in Responsive Applications with BLE and RTC sleep mode.
Designed as a Raspberry Pi Zero HAT.

DESIGN NOTE:
Example text for informational
design notes.

Example text for critical

pira-smart-PCB.PrjPcb
PAGE1-CONTENTS.SchDoc

LAYOUT NOTE:
layout guidelines.

Size: | DWG NO | Revision: v2_1

* Date: | 1 2 Sheet of

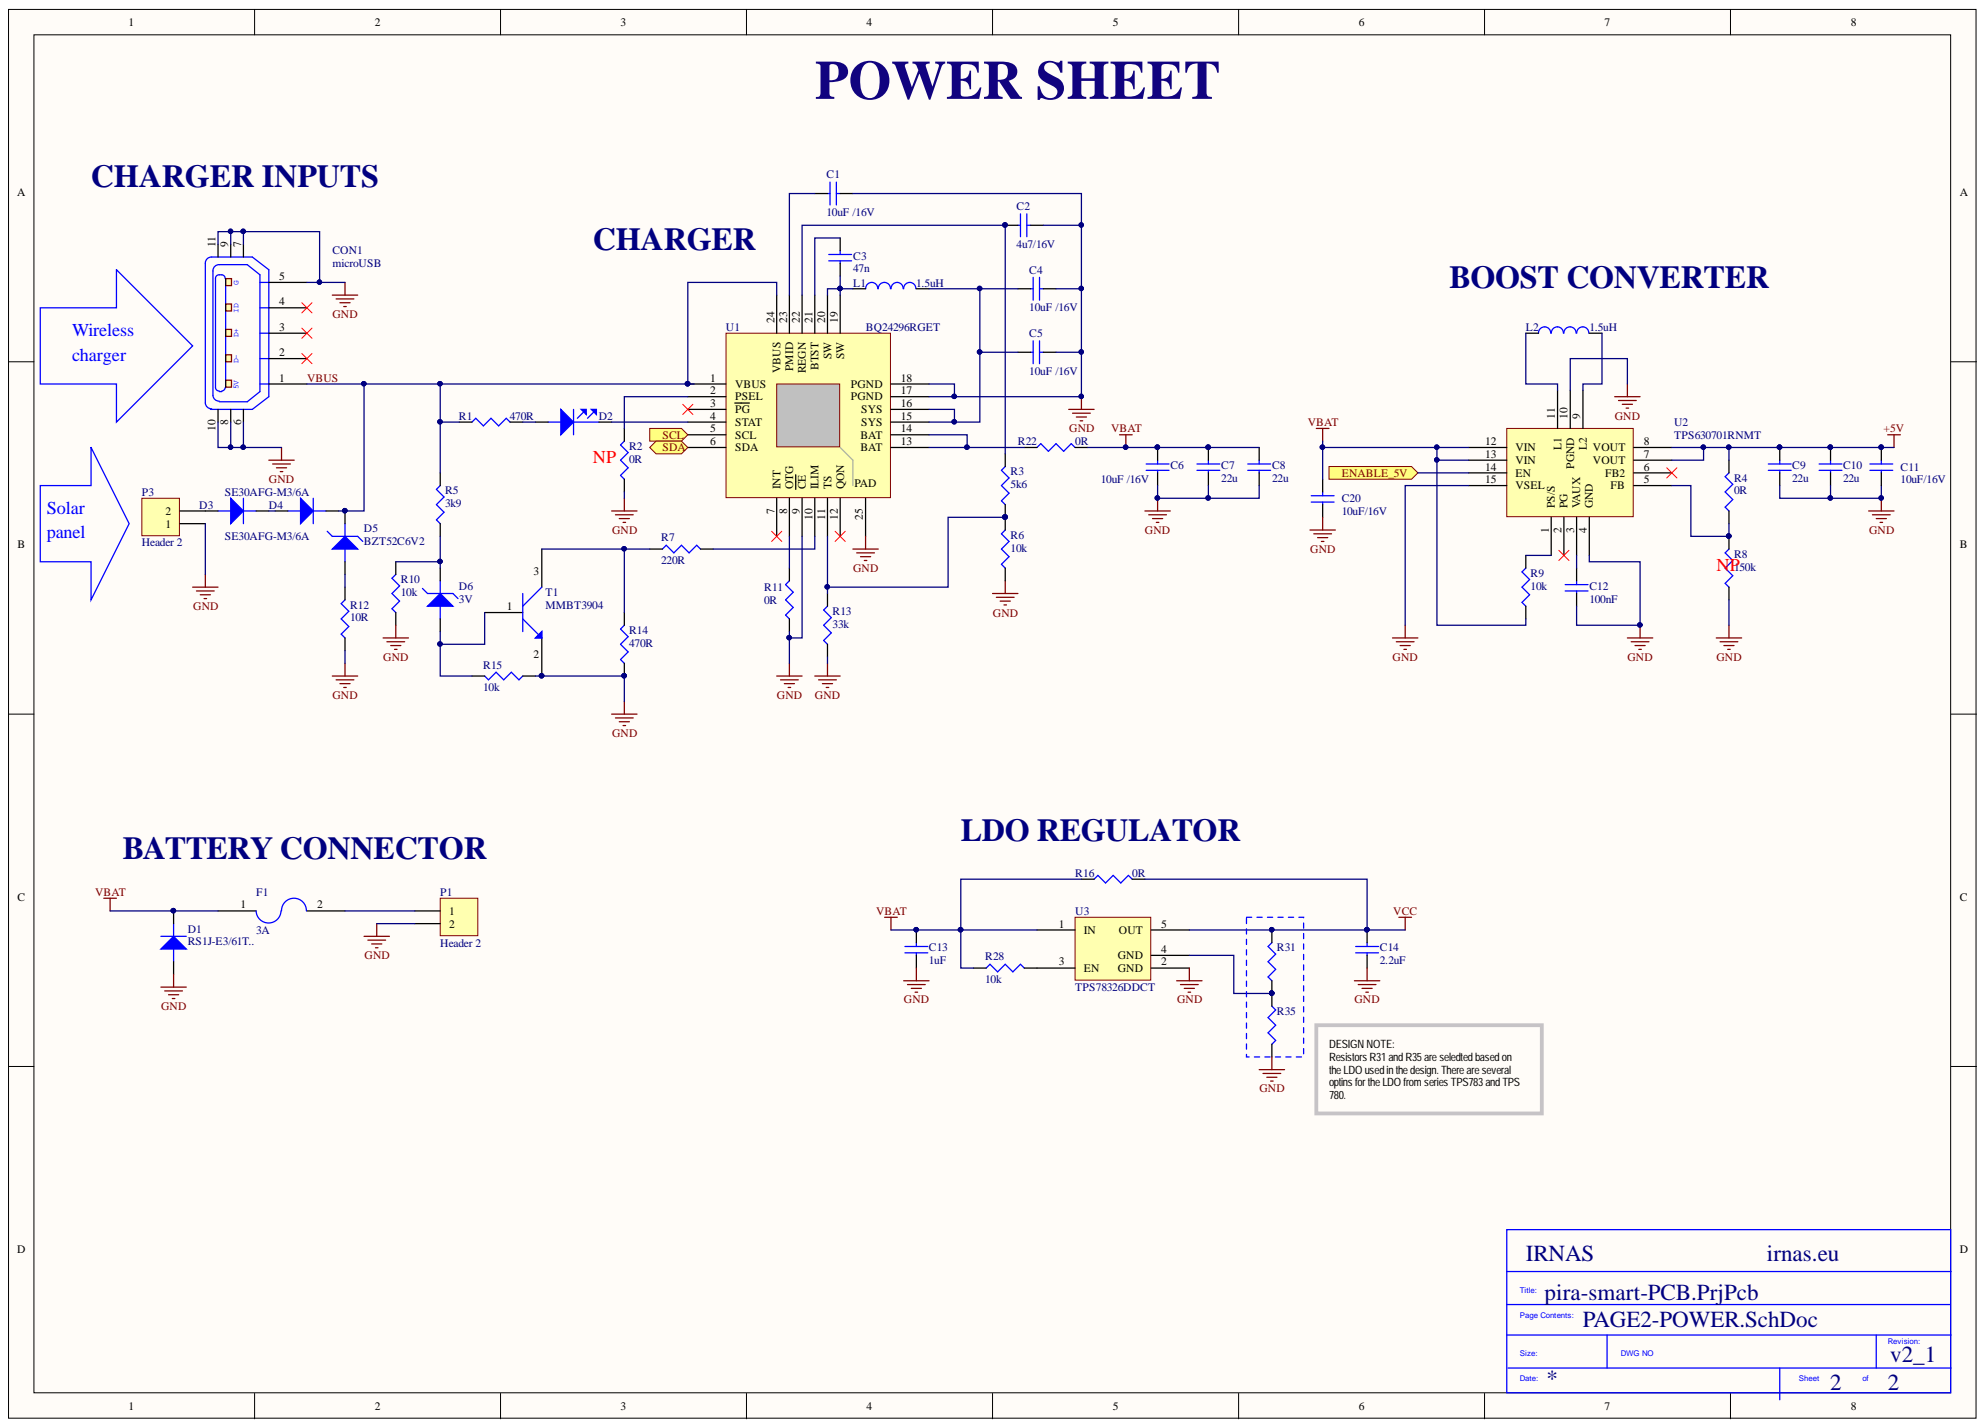
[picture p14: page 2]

SW 19 SW 20 BTST 21 REGN 22 PMID 23 VBUS 24

SCL 5

VIN 13
EN 14 VSEL 15

DESIGN NOTE:
Resistors R31 and R35 are seledted based on
the LDO used in the design. There are several
optins for the LDO from series TPS783 and TPS

pira-smart-PCB.PrjPcb
PAGE2-POWER.SchDoc

Revision: v2_1

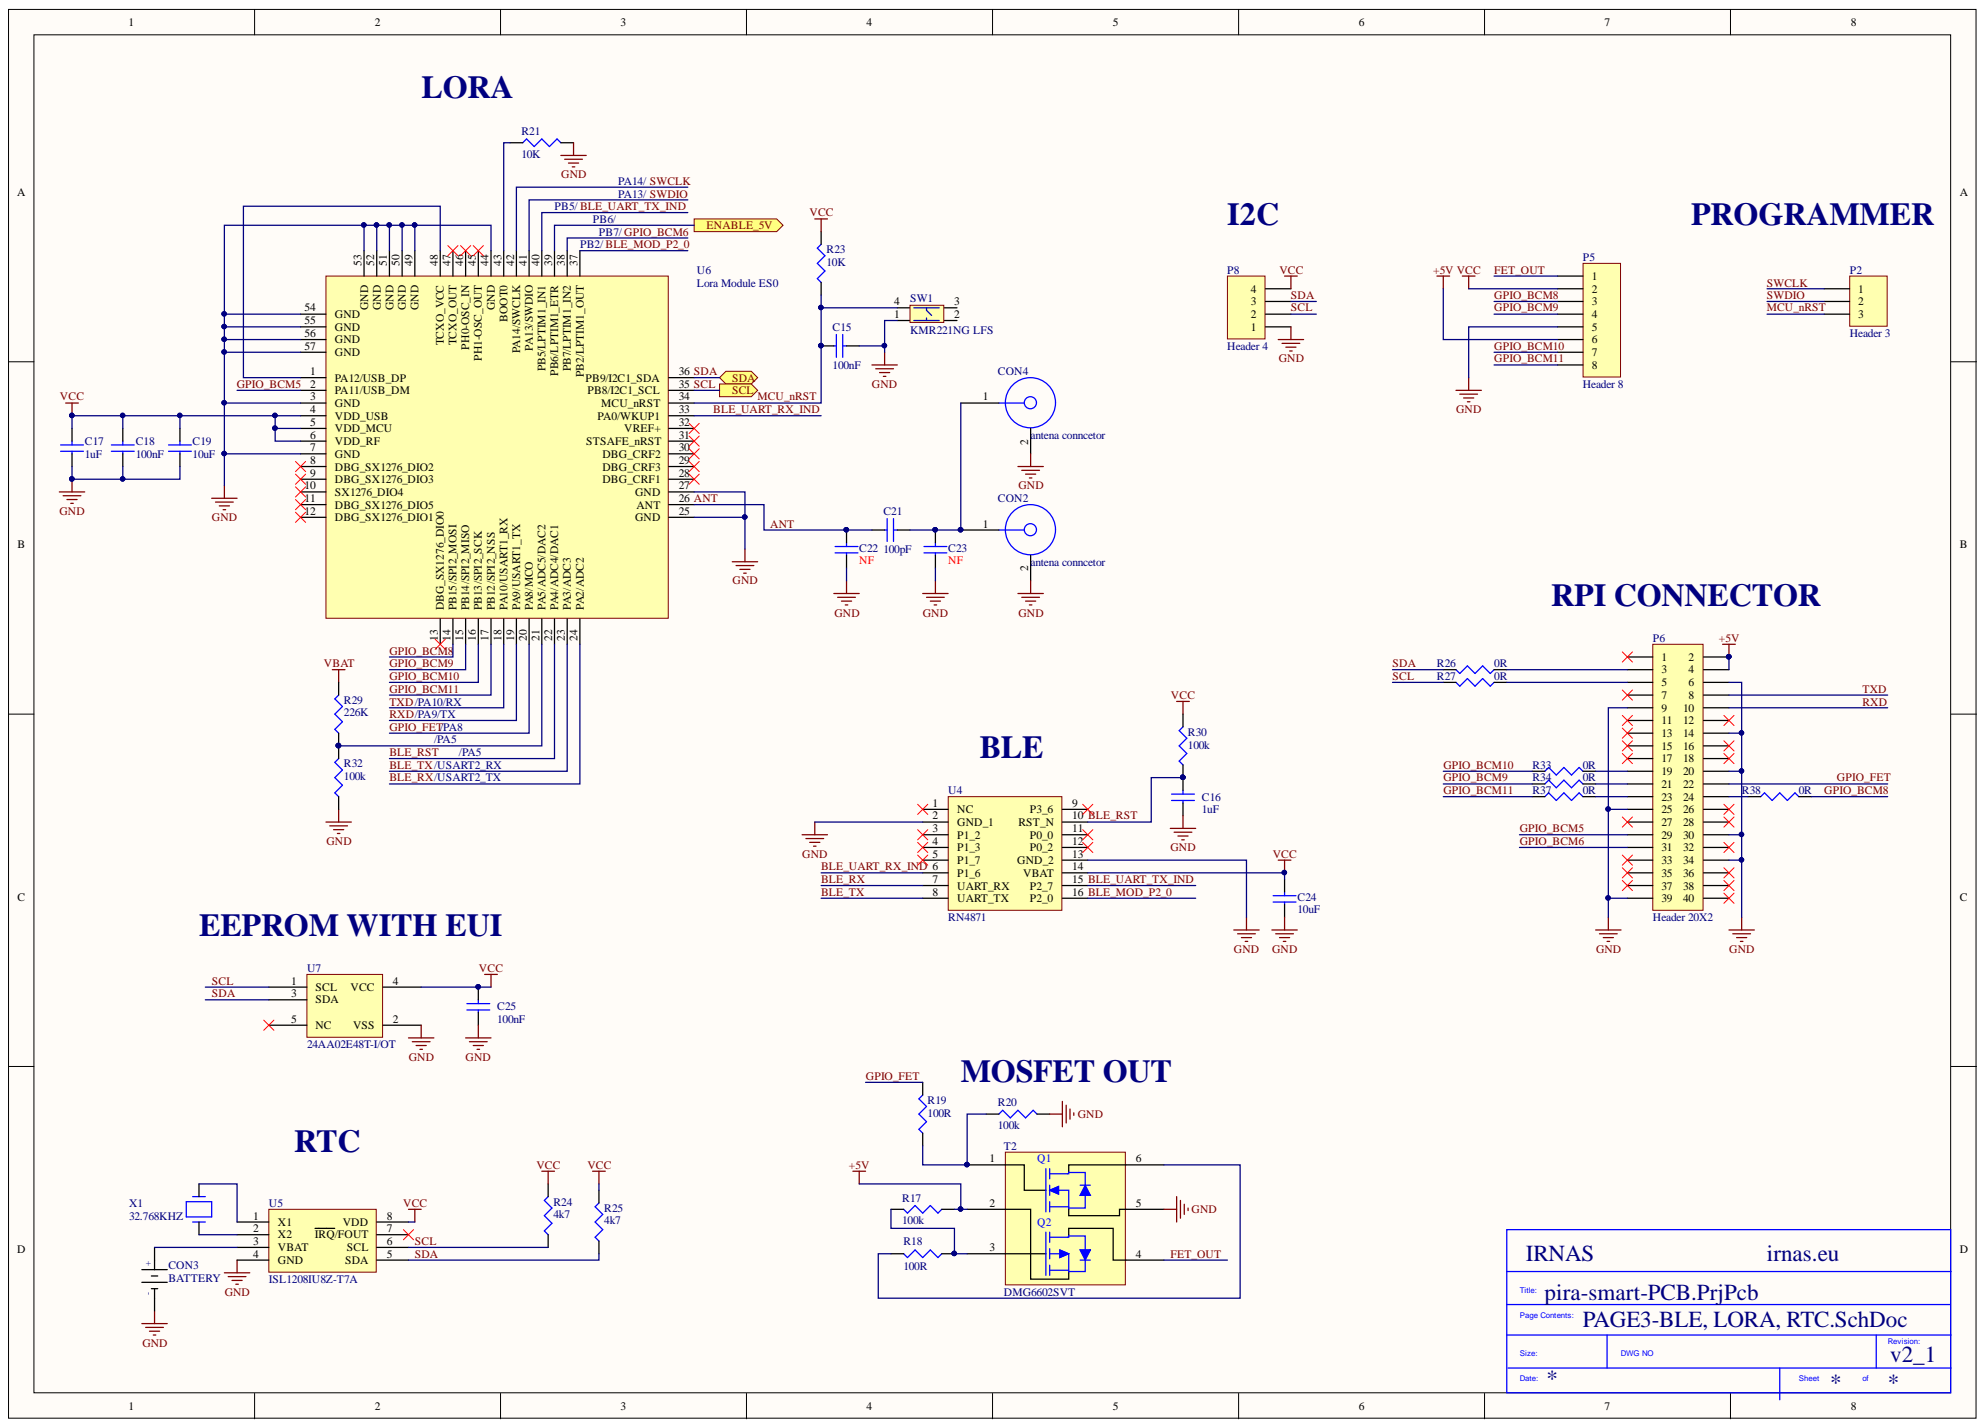
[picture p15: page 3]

GND 50 GND 51 GND 52 GND 53

VDD_USB 4 | BLE_UART_RX_IND
VDD_MCU 5
VDD_RF 6

DBG_SX1276_DIO5 11 | ANT
DBG_SX1276_DIO1 12 | | ANT

pira-smart-PCB.PrjPcb
PAGE3-BLE, LORA, RTC.SchDoc

Revision: v2_1

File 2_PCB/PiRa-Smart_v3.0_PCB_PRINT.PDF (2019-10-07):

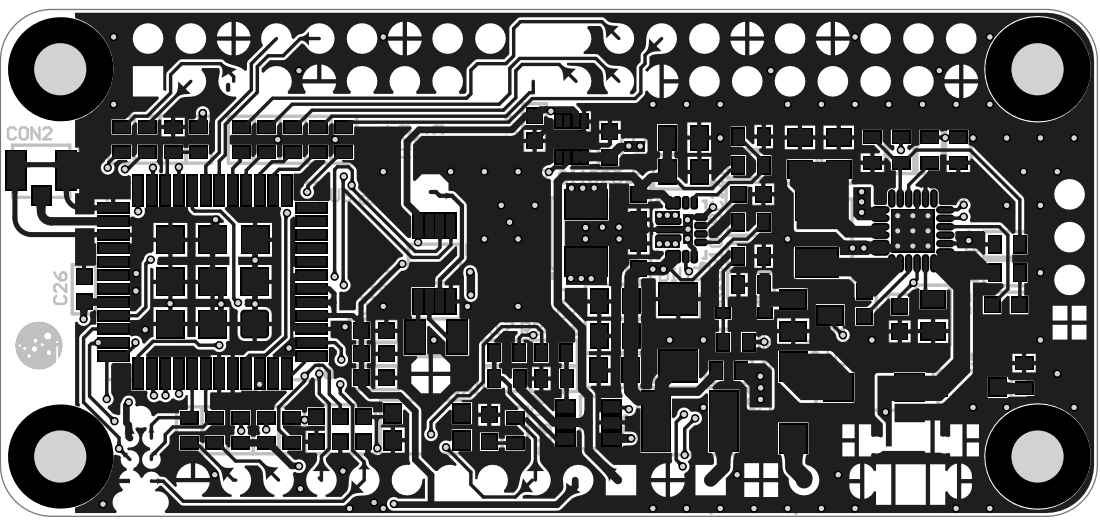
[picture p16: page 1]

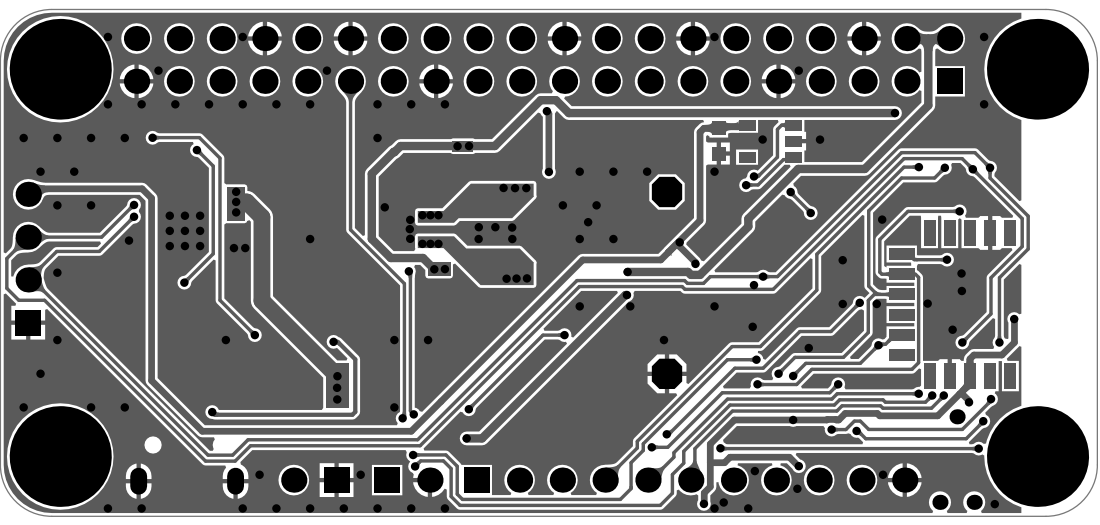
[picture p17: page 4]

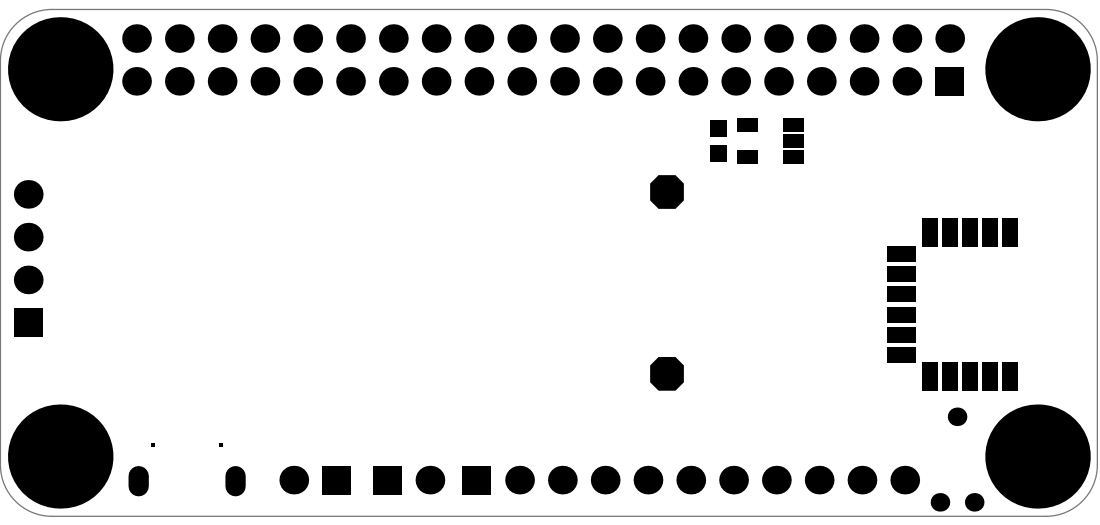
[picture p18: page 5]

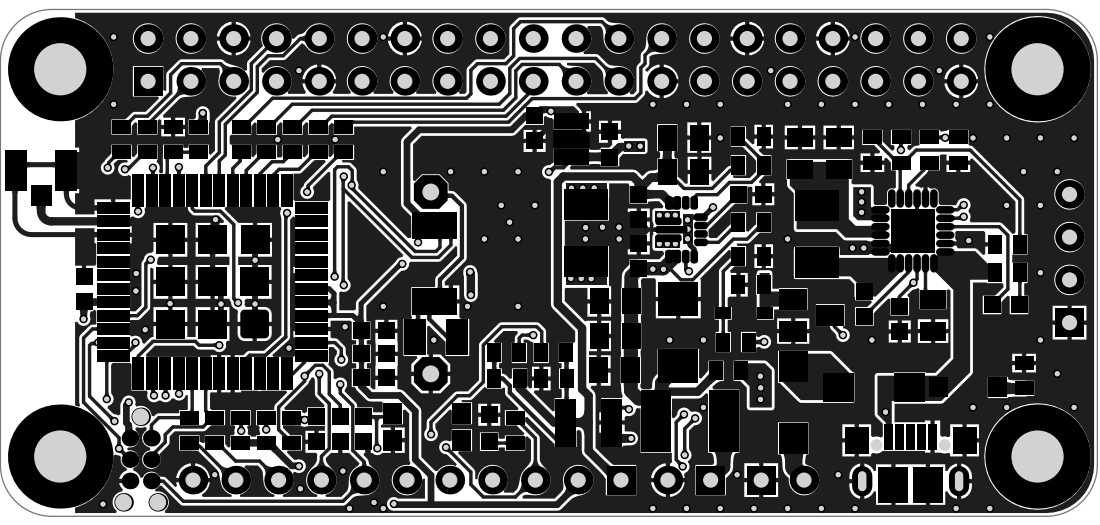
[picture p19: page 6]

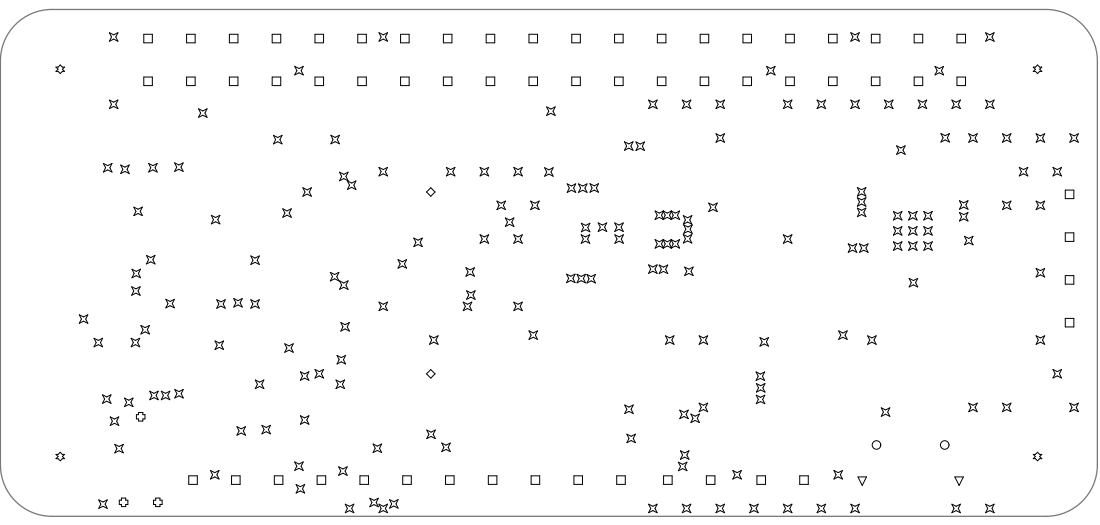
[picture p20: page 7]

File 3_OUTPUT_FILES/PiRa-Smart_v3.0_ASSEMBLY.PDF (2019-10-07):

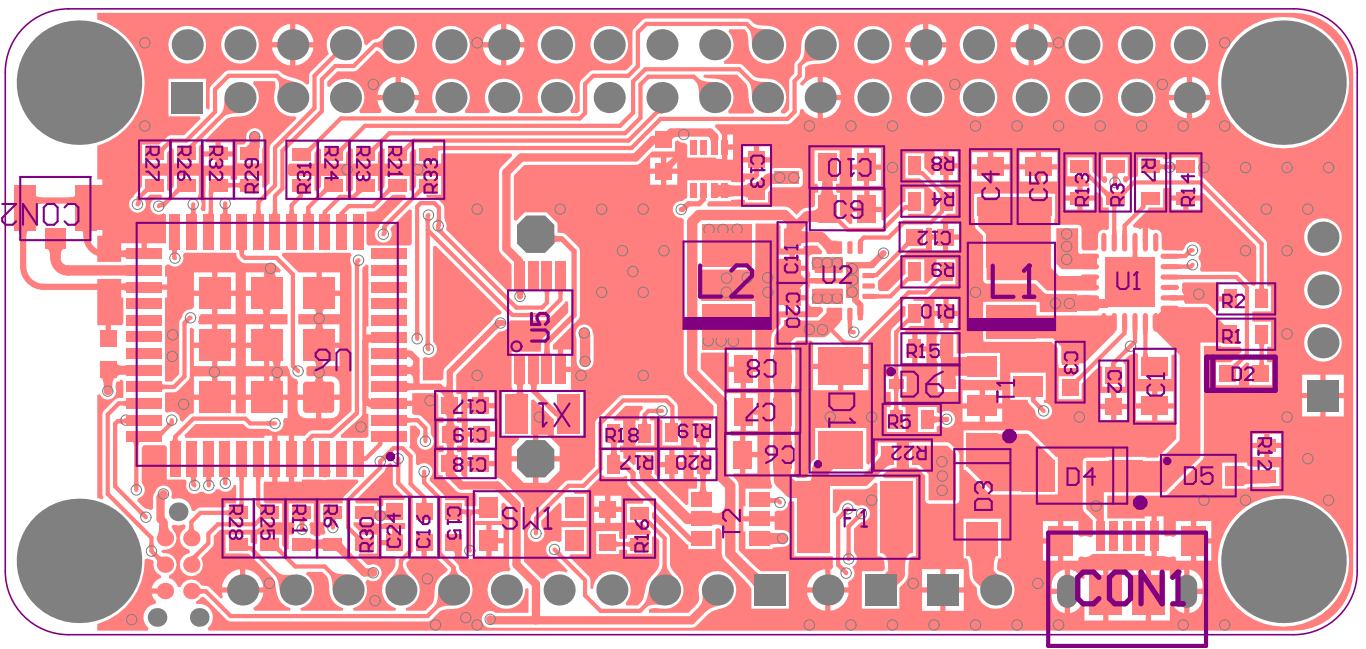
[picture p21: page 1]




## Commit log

2018-11-19 Altium project files Pira-v2.0
    [Bill of Materials production-pira-smart-PCB.xlsx, EDI2CAP.CFG, MDBT40-2D Drawing-20150402.dwg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]
2018-11-20 Added murata lora module and RN481
    [EDI2CAP.CFG, PADS Libraries.PrjPcb, PAGE1-CONTENTS.SchDoc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]
2018-11-24 Pira-smart 2.0 routing completed
    [PAGE2-BLE, POWER, LORA.SchDoc, User Library-CR2032-VCN.STEP, User Library-Module_Microchip_RN4871.STEP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]
2018-11-26 Silk mask modified
    [PAGE2-BLE, POWER, LORA.SchDoc, pira-smart-schlib.SchLib]
2018-11-28 Schematic changed, added resistors, jumper and capacitor. SPI pins changed for GPIOs. Mosfets are now on bottom layer.
    [PAGE2-BLE, POWER, LORA.SchDoc, PAGE2-POWER.SchDoc, PAGE3-BLE, LORA, RTC.SchDoc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]
2018-11-30 Minor changes to PCB layout, changed thickess of some traces
2019-03-20 add docs
    [PAGE3-BLE, LORA, RTC.SchDoc, pira-smart-PCB.PrjPcb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]
2019-03-28 release docs for v2_1
    [BOM-pira-smart-PCB.xls, BOM-pira-smart-PCB.xlsx, PAGE1-CONTENTS.SchDoc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]
2019-09-12 added last changes before v3.0
    [BOM-pira-smart-PCB.xls, BOM-pira-smart-PCB.xlsx, Bill of Materials production-pira-smart-PCB.xlsx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]
2019-10-07 Update documents
    [PAGE1-CONTENTS.SchDoc, PAGE2-POWER.SchDoc, PAGE3-BLE, LORA, RTC.SchDoc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]
